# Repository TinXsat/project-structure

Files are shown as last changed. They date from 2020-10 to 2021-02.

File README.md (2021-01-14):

# project-structure

This repo is purely for discussing and planning the whole project's structure - what will communicate with what and how, how software will be organised, etc - whole "schema"

### Contributing :pencil:
All discusion and changes will be done through Pull Requests and Issues - commiting directly to master is officially illegal here  :no_entry_sign: :hand: :no_entry:

<sub><sub>[Inserting emojis](https://gist.github.com/rxaviers/7360908) into every single header is also required, and not respecting that will be punished 🔪 </sub></sub>

<!-- START doctoc generated TOC please keep comment here to allow auto update -->
<!-- DON'T EDIT THIS SECTION, INSTEAD RE-RUN doctoc TO UPDATE -->
**Table of Contents**

- [Mission :rainbow:](#mission-rainbow)
  - [Measurements of atmospheric pressure and temperature with subsequent data analysis :thermometer:](#measurements-of-atmospheric-pressure-and-temperature-with-subsequent-data-analysis-thermometer)
    - [Key goals :key:](#key-goals-key)
  - [Demonstration of cansat system for rescue operations during natural disasters :volcano:](#demonstration-of-cansat-system-for-rescue-operations-during-natural-disasters-volcano)
    - [Key goals :key:](#key-goals-key-1)
    - [Optional goals :small_blue_diamond:](#optional-goals-small_blue_diamond)
- [Satellite :satellite:](#satellite-satellite)
  - [Satellite launch :rocket:](#satellite-launch-rocket)
  - [Sensors aboard :thermometer:](#sensors-aboard-thermometer)
  - [Satellite 2 ground communication :phone:](#satellite-2-ground-communication-phone)
- [Ground station :radio:](#ground-station-radio)
- [Ground back-end server :computer:](#ground-back-end-server-computer)
- [Front-end :iphone:](#front-end-iphone)
- [Further data analisys :bar_chart:](#further-data-analisys-bar_chart)
- [Gantt timeline chart :alarm_clock:](#gantt-timeline-chart-alarm_clock)

<!-- END doctoc generated TOC please keep comment here to allow auto update -->

# Mission :rainbow:
## Measurements of atmospheric pressure and temperature with subsequent data analysis :thermometer:

### Key goals :key:

 - Measure of pressure and temperature outside the cansat.
 - Radio transmission of measurements data in minimal rate one packet per second.
 - Calculation of altitude based on atmospheric pressure.

## Demonstration of cansat system for rescue operations during natural disasters :volcano:

### Key goals :key:

 - Design system that meet following requirements:
 - low cost of produce
 - high accuracy
 - Access to information about position(GPS), altitude (barometer), temperature, acceleration
 - Take photos from the thermovision and visible range camera.
 - Mark on photos all obstacles (to protect rescuers) and places where people could possibly be.

### Optional goals :small_blue_diamond:

 - Investigate fire resistant biofiber composite with which body of cansat will be build
 - Pointing geographical coordinates of marked obstacles/humans.

# Satellite :satellite:
How the cansat sattelite will look and work to help us do the mission?

## Satellite launch :rocket:
How we will actually launching the sattelite (that is take it to 1.5km above)?

## Sensors aboard :thermometer:

## Satellite 2 ground communication :phone:
How our satellite will communicate with the ground station?

# Ground station :radio:
What is ground station and how it will work and pass us *the data* :chart_with_upwards_trend:?

# Ground back-end server :computer:
[Back-end server](https://github.com/TinXsat/server) takes care of receiving data from [ground station](#ground-station-radio),
parsing and processing it, and serving it to the [front-end](#front-end-iphone).
It also caches and saves any data that it received, in case satellite would fall apart

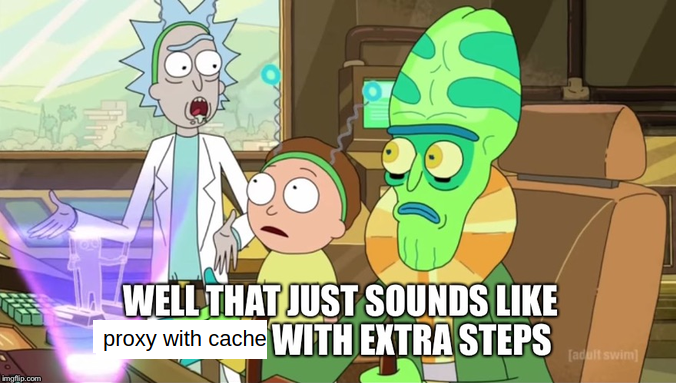
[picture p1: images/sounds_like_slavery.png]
Sounds like proxy+cache with extra steps


It is written in [Python](https://www.python.org/), and uses [Flask](https://flask.palletsprojects.com/) to serve a REST API

# Front-end :iphone:
[Our front-end](https://github.com/TinXsat/frontend) is a dashboard that will show us what is currently happening with the sattelite while it's in the air - for example, a map showing where the sattelite is right now, animation (like at SpaceX) about in what stage of the mission it currently is, etc

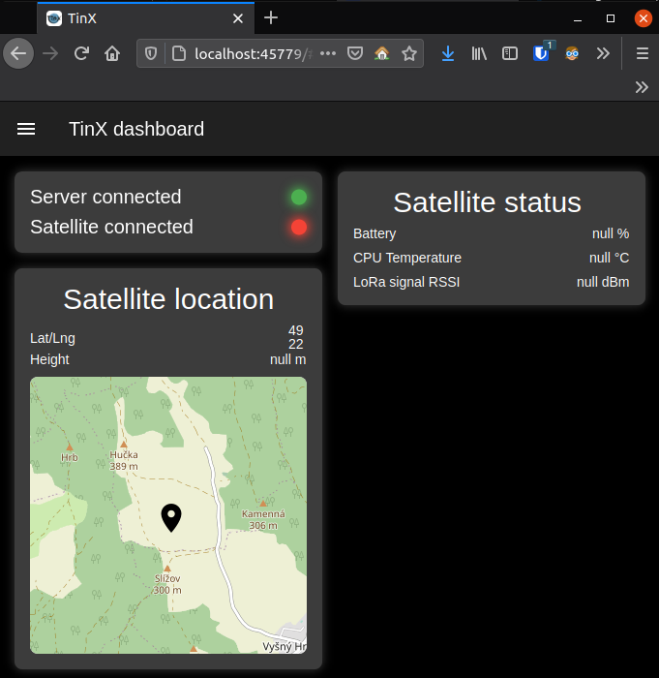
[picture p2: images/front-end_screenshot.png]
Screenshot of front-end


It is built in Flutter, and compiled to a web app. It gets data form [the server](#ground-back-end-server-computer) through REST endpoints, probably instantly, through localhost, since they will be hosted on same computer

# Further data analisys :bar_chart:
What we will further do with *the data* beyond the elements above?

# Gantt timeline chart :alarm_clock:

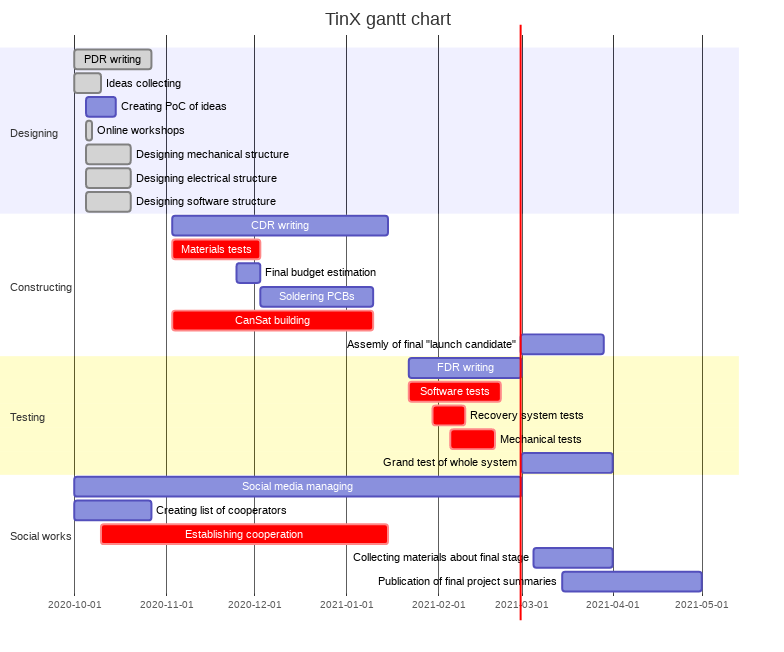
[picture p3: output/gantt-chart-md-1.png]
~mermaid diagram 1~


// You can view the code-block it in [gantt-chart.md](gantt-chart.md)

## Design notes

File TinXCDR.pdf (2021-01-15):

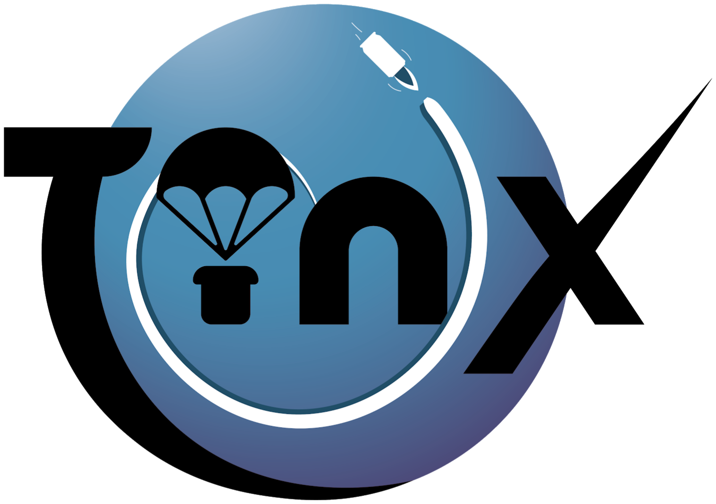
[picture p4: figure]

## TinX

## Technical High School no. 6 in Rzeszów

## Critical Design Review

CHANGELOG

3
INTRODUCTION

3
Team organisation and roles

3
Mission objectives

6
CANSAT DESCRIPTION

7
Mission overview

7
Mechanical/structural design

8
Electrical design

9
Software design | 18
Satellite software design | 18
Ground station software design | 20
Data analysis | 22
Recovery system | 23
Ground support equipment | 23
TEST CAMPAIGN | 24
Primary mission tests | 24
Secondary mission tests | 24
Communication system | 26
PROJECT PLANNING | 26
Time schedule | 26
Task list | 27
Budget | 27

External support | 28
Outreach programme | 28
CANSAT CHARACTERISTICS | 30

## CHANGELOG

## 1. INTRODUCTION

### 1.1. Team organisation and roles

Due to COVID-19 pandemic team started working online. We’re planning CanSat development during meetings on discord platform. Each team member dedicates one hour per week during meetings and members are prepared to dedicate needed time in after school time.

- 3 -
Date | Description | Page
2020-11-15 | Change goals for secondary mission | 6
2020-11-19 | New team member Aleksy Malawski | 6
2020-12-18 | Exclude inertial dampers | 8

- Ms. Anna Pękala (teacher)
Background:
Ms. Pękala has a Masters in Economics, and is a certified career counsellor. She has 15 years working experience with students in the fields of basic economics, entrepreneurship and career planning. Ms. Pękala has a number of interests, these include economics, psychology and personal development.
Field of work within team:
Ms. Pękala will be responsible for work planning and assignment of tasks. She will also be responsible for helping to motivate team members so that they can deliver their best work on this project. Ms. Pękala will also help members of the team to develop and grow through this process.
Ms. Pękala will also assist in management of the budget for this project, and assist in fundraising as necessary.
- Mikołaj Data (Team Leader).
Background :
Mikołaj Data is a student of Technical High School no. 6 in Rzeszów. He has extensive knowledge in the fields of programming, data analysis, electronics and astronautics. He has 6 years of experience in IT. Languages mainly used by him are C and Python.
Field of work with team:
He will be responsible for work planning, software and electronic development. His duties will also include website and social media managing.
- Przemysław Lib
- 4 -

Background :
Przemysław Lib is a 3D designer with many years of experience. Inventing useful devices and mechanisms is his passion. The programs he uses are Fusion 360 and Simplify 3D. He is a student of Technical High School no. 6 in Reszów.
Field of work with team:
His main task is to develop a safe recovery system, design CanSat’s body. He is also responsible for finding financial support in external sources.
- Filip Różak
Background:
Filip Różak has experience in designing and troubleshooting electronic devices from different fields: RF circuitry, SMPS, industrial, production, automation. Furthermore, he develops software for microcontrollers such as AVR, PIC, ARM mainly in the C language. He has great interest in creating robust and cheap solutions for everyone. Filip Różak is a student of Technical High School no. 6 in Rzeszów.
Fields of work with team:
His main task is to make design decisions about electronics in CanSat, develop schematics, circuit board(s) and write applications for onboard microcontrollers.
- Mateusz Soszyński
Background:
He is a full stack developer - has experience in many different aspects of programming - from embedded devices, to mobile apps, to managing Linux servers. He is also a passionate open-source community member, so he will be the most active in managing and maintaining our GitHub repositories.
- 5 -

Fields of work with team:
His main task is to take care of handling the data from satellites on the ground - processing and analyzing it on the back-end, and displaying it on the front-end.
- Aleksy Malawski
Background:
He is a graphic and motion designer. He is interested in animation and film editing. He has experience taking up many logos, illustration and motion design projects. Mostly creates his works using Adobe Illustrator and After Effects.
Fields of work with team:
He's responsible for creating posts, films and animation for teams' social media platforms.

### 1.2. Mission objectives

Due to some problems with cost of elements and COVID-19 pandemic, few of our goals was changed (see PDR report to see previous goals)
Primary mission: Measurements of atmospheric pressure and temperature with subsequent data analysis.
Key goals:
- Measurement of pressure and temperature outside the CanSat.
- Radio transmission of measured data in minimal rate one packet per second.
- Calculation of altitude based on atmospheric pressure assisted with geolocalization data.
- 6 -

- Measurement of temperature inside and outside the CanSat. To provide data about electronic parts performance.
Secondary mission: Demonstration of CanSat system for rescue operations during natural disasters.
Key goals:
- Design system that meet following requirements:
- Low cost of design and produce
- High accuracy and stability
- Easy access to information about position, altitude, temperature, acceleration
- Take photos from the visible range camera - and analyze them.
Optional goals:
- Investigate a fire resistant biofiber composite with which body of CanSat will be built, keeping cost as low as possible.
- Create an open access dataset for aerial photography classification.

## 2. CANSAT DESCRIPTION

### 2.1. Mission overview

Mankind is more often a bystander of natural disasters caused by global warming. Our project is focused on helping rescue teams during their hard work. Data gathered during the mission will be available for other engineers, scientists to help them improve their solutions.
The mission is being developed through a CanSat competition. Organisers of the competition provide a take-out system (rocket or UAV). CanSat on-board computer start is planned for +/- 2 hours before take-off. During take-off the satellite accelerometer will inform the on-board computer about rocket launch, then the
- 7 -primary mission starts. When CanSat will be deployed the secondary mission starts. Landing is predicted 4 minutes after deployment.

### 2.2. Mechanical/structural design

General objectives for the mechanical structure of the CanSat:
1. We will introduce the construction of CanSat inertial dampers to protect sensitive electronics, such as cameras, against vibrations and high acceleration stresses. - Canceled
2. The internal frame with electronics will be covered in a semi-fireproof shell made of fibers and ceramics.- Canceled
3. The internal frame will be printed with 3D technology, using nylon or materials with similar properties.- Included
4. Sensors will be placed in the external shell and will be connected by flexible wires to the main board.- Included

During development, we decided to exclude
dampers from the project. Tests showed that
small rubber pieces don't work as well as we
expected, | moreover | it | complicates | the
production process too much and weakens the connection between PCB bracket and internal frame of the canstat.
CanSats body still will be based on an internal PCB bracket screwed to the internal frame, but we recognised that our fireproof material is too heavy to use in cansat project. We made several different versions of fireproof material based on natural fibers but all of them were heavier than our assumptions. Instead of this we decided to use the
- 8 -

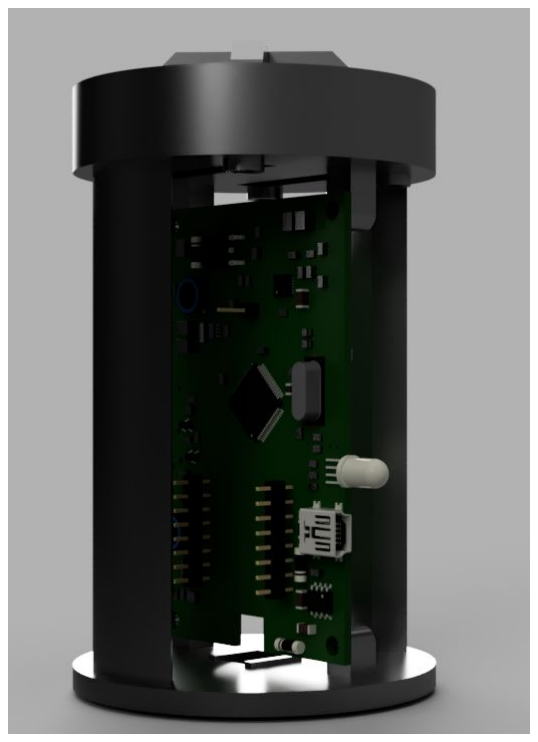
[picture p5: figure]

same material like we used to make canstats frames, that material is nylon reinforced with glass fibers.
During tests nylon reinforced with glass fibers met our expectation so we will use it in the final version of CanSat. That material will be used to make a PCB bracket, internal frame and also external body which will cover electronics and sensors. Sensors like barometer or thermometer will be glued with thermo-plastic glue to the external body. Barometers have to be protected against rush of air during the falling so we designed special channels which keep sensors inside of the case but also deliver atmospheric pressure to them.

## 2.3. Electrical design

General architecture
Electronic part of Cansat has been optimized for low-cost, highly efficient and fail-safe production process, assembly and operation. Usage of Off-the-shelf components has a significant impact on overall cost and opens a very cheap way to mass production.
Power supply
When in operation, device will be powered from li-on cells. This chemistry was chosen, because it’s comparably safe, operates well enough in a wide temperature range, is widely available, inexpensive and comes in almost every physical shape. To save space inside, flat (eg. phone) style batteries are used.
Li-on cells need to be charged properly - in CC and CV modes. Exceeding any of their normal parameters will decrease battery capacity and possibly damage the cells (or even the whole device due to explosion/leakage). Used batteries have protection circuits integrated inside. It protects individual cells against:
1. Over current discharge protection
2. Over discharge protection
- 9 -

To cover all of the battery requirements, also charging voltage and current has to be regulated. Most of this is done with just one physical chip (TP4056), which is a very common, cheap and trusted li-on cell charger. It does CC/CV modes switching, over charge protection.

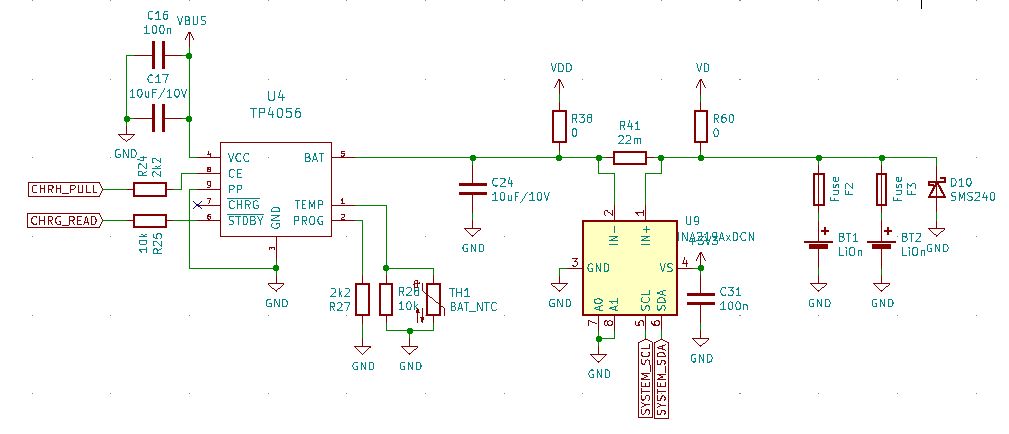
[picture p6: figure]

This part of the schematic shows the battery charging and monitoring system. F2 and F3 polyfuses protect against overcurrent/short circuit, if battery without protection inside is used. D10 protects circuit against connecting battery backwards. U9 measures battery voltage and current (using R41 shunt). U4 is an integrated charger with control/status pins connected to a microcontroller. Battery level can be estimated from voltage measured on battery (using U9) and/or calculating charged/discharged energy from battery.
Power management:
To optimize battery live - INA219 integrated bidirectional voltage/current sensors will be used. It makes power monitoring simple, reliable and cheap. INA219 has an integrated A/D converter and PGA, thus no additional analog components are not needed. This leads to very low price and efficient usage of PCB space (<1cm^2 for
- 10 -complete current/voltage measurement). Two of such monitors has been used across the board:
1. Measures battery charged/discharged current and battery voltage.
2. Measures battery voltage and current took by high voltage devices (Led Light and buzzer)
Creating System voltage rails:
Most of the IC’s on the board (including main controller) operate on 3.3V - thus there is a need of creating stable, reliable supply rail. To operate on the whole battery capacity - voltage must be stepped up (VBAT < 3.3V) or stepped down (VBAT > 3.3V). This can be achieved by using Buck-Boost converters such as TPS63001. It has integrated switches, automatic mode (Buck/Boost/passthrough) selection, Enable input (used to completely power off device) and operates on single, physically small inductor (due to high switching frequency: 1,2-1,5Mhz). At currents >100mA estimated efficiency of this converter is >80%.

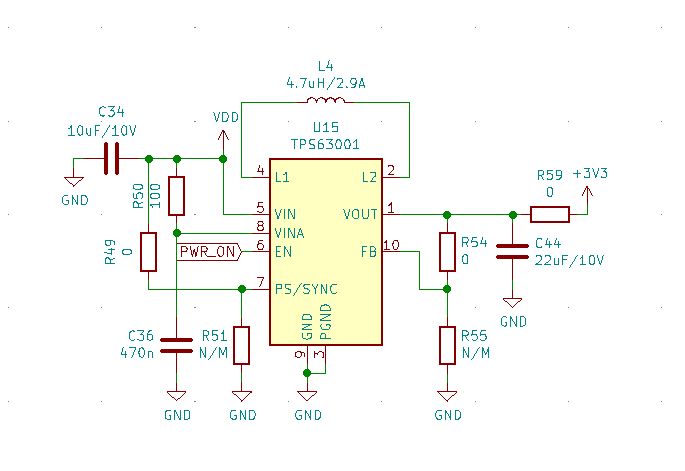
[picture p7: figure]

Creating 3.3V rail is very simple, and thus reliable using such an integrated converter. Low external components count minimizes board space taken by power management, to let more room for other circuitry.

- 11 -

To power Led Lightning with approx. 15V, stepping up of the voltage is needed (buzzer is also powered from this rail). TPS61175 integrated Step-up is used for this purpose. It’s small and simple to implement, guarantees high efficiency (>85%).

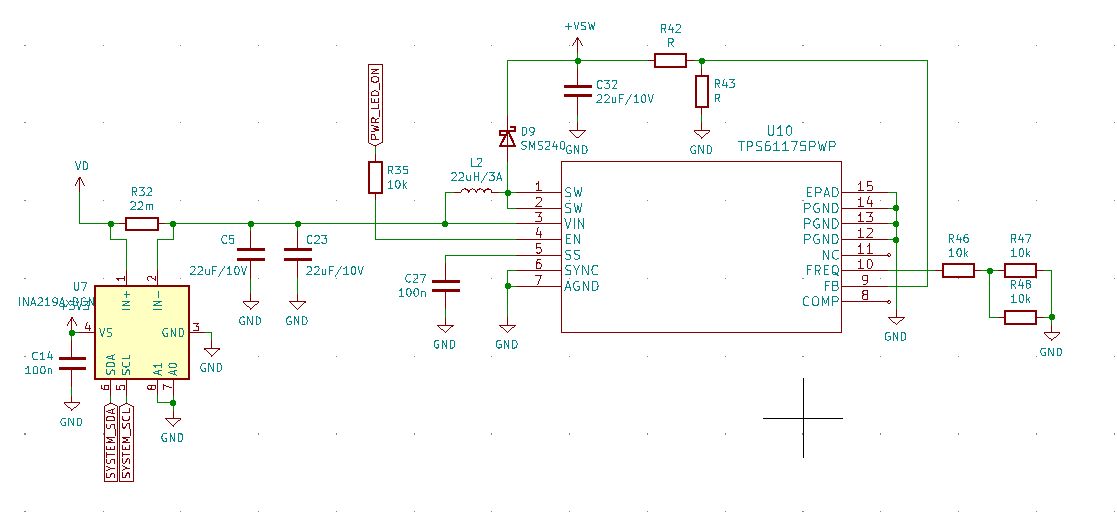
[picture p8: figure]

To keep EMI at a low level, and not disturb sensors in the device (or even other devices), proper layout of switching converters must be utilized.

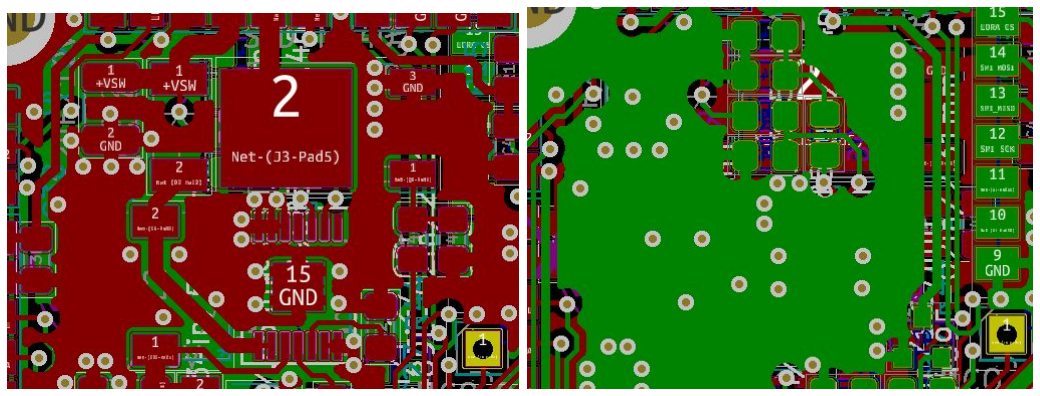
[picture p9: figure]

1. Ground plane under most noisy traces
2. Thick ground connection to switching components and bypass capacitors.
3. No analog traces near the converter
4. Concise structure of the whole converter.
- 12 -

Power-up logic:
In order to make the device operate only, when needed (save battery during transport and so on), power-up logic is implemented. To switch the device off, 3.3V converter “Enable” input is used.

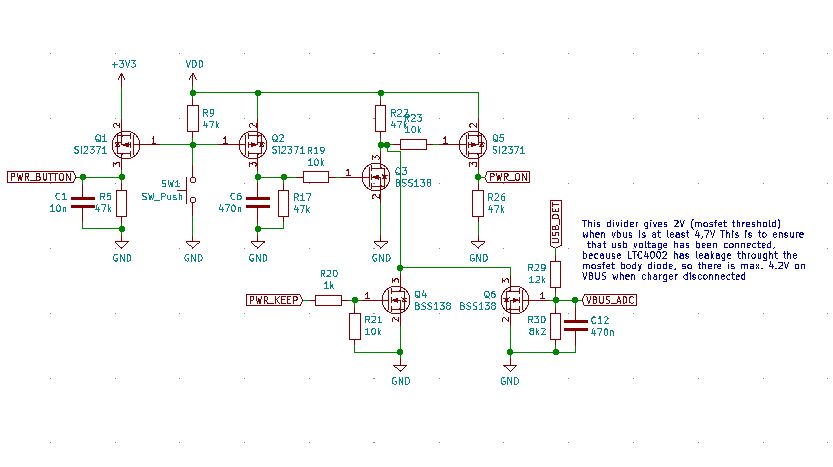
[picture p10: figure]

Microcontroller (and other circuitry on 3.3V rail) is powered only if:
1. Momentary button is pressed
2. Processor supplies power to itself
3. USB charging port is connected
This approach makes power-on sequence very reliable - cansat can be turned on by a momentary button, then a microcontroller starts up and latches power to itself (PWR_KEEP signal). Then - button can be used to power cansat down, but this function will be enabled only after the mission or corresponding lora command. This makes sure that no false power off will be triggered. Microcontroller also operates, when the USB charging port is connected - to show battery level on status LED, and integrate power injected to battery.
- 13 -

Estimating needed battery:
All values are maximal, worst case (in exact mode). Needed operating time is 3h in operation and 10h in standby (beacon).
- 14 -
Component | Operation | Standby
BMP280 x2 (Pressure + Temp) | 19uA * 200Hz = 3,8mA | 2,7uA
MPU6050 (Gyro+Accel) | 3,9mA | 500uA
A25l032 (Flash) | 21mA | 15uA
STM32F103RGT6 | 70mA (impossible - all pheripherials enabled, max speed) | 15uA
INA219 x2 (current measurement) | 1mA | 15uA
ESP32-CAM | 200mA | 20uA
Lora SX1278 | 120mA | 1.5u
Led lightning | 700mA 2/5 duty = 140mA | -
TPS63001 | 60uA | 1uA
TPS61175 | 3.5mA | 1.5uA
Buzzer circuit | 5mA | -
CP2102 | 26mA | 100uA
TP4056 | 6uA (from battery) | 6uA (from battery)
Genuine GPS receiver | 5mA | 200uA

We could do further calculations, but this data is not reliable - we are estimating power consumption of ~350mA when in operation and 2mA standby. Two 1,5Wh 3,7V Li-On cells with protection are used. Tests will show real values of consumed power.
Primary mission devices:
Primary mission of the device is to acquire temperature, pressure values, store them with altitude information and let the user read the data using a memory card. Radio communication will occur at least 1 time per second.
To measure Altitude and atmospheric pressure BMP280 sensors are used due to their numerous advantages:
1. Low cost
2. High reliability (tested in millions of devices)
3. Fast Data acquisition
4. Low power consumption
5. Simple to implement: I2C communication
6. Accurate enough, factory calibrated
To improve temperature data collection in speed domain (and relative accuracy) additional external sensors (LM35) are used - they have analog output and are physically small, this allows measurement of very fast temperature changes outside the device.
Main controller has been chosen, based on:
1. Low price
2. Good availability
3. Ease of programming/development. Evaluation board for this family exists.
- 15 -
Sum | 510mA | 1,4mA

4. Long production live (+10 years guaranteed)
5. Enough resources for possible expanding functionality
To meet all of the above, STM32F103RGT6 microcontroller has been selected. It has Cortex-M3 core, and a handful of useful pheripherials. It’s maximum frequency is 72Mhz on the core, and 36Mhz on fast periphs. All the inputs/supply pins operate at 3V3 logic levels, as well as every other chip on the board, so no level shifters are needed. This microcontroller also has automotive temperature range, clock save system and reliable BOR circuitry.
Secondary mission devices
Main goal of the secondary mission is
to make photos from the air, for further analysis. Usage of off-the-shelf cameras is not cheap enough for this device. However cheap ESP32-cam modules are available, they have reasonable capabilities compared to their very low price. Such modules integrate ESP32 processor together with external flash memory for firmware and camera connection. The
OV2640 camera can be used with the
module directly - it’s small, has 2Mpx

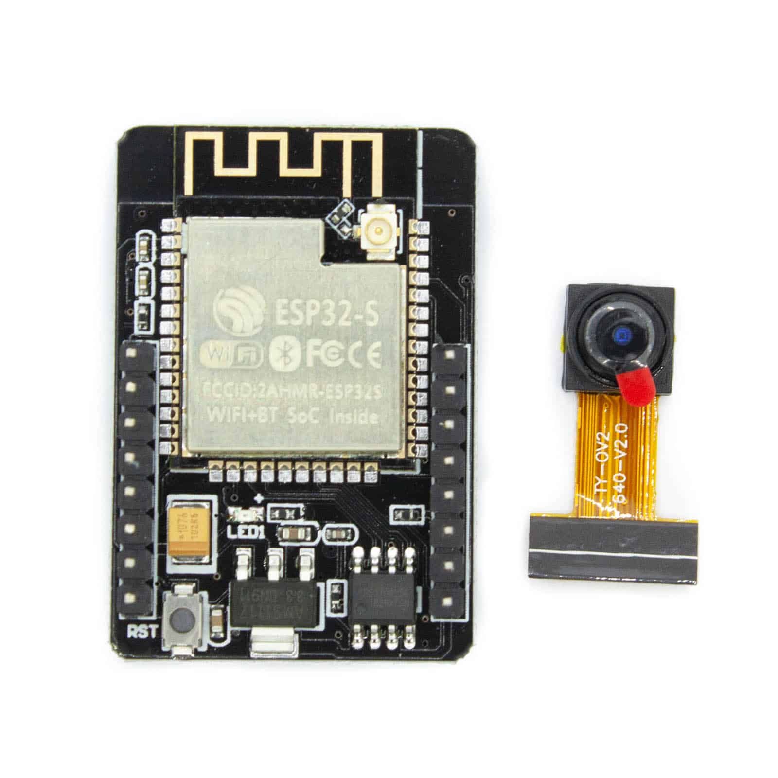
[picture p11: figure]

resolution and is very cheap. Usage of a secondary processor just for image handling is very efficient, because it has to be done as fast as possible and not interfere with other tasks. Images will be directly saved on memory card, due to their enormous size.
To obtain device rotation and acceleration in three-dimensional space (this is needed to determine mission phase and camera pointing direction), a gyroscope
- 16 -and accelerometer is used. MPU 5060 has been chosen due to it’s small physical dimensions, speed (measurement up to 1Khz) and low price. To achieve this performance, a separate I2C bus has been occupied as well as dedicated interrupt pin as well as frame synchronisation.
To obtain device geolocation position, a generic Telit GPS module is used. It uses a supercapacitor to keep satellite data in RAM, this allows for hot-start of the Receiver and makes overall fix time faster. Communication with the module is one-way.
All data, excluding photos, are saved to on-board flash memory - A25l032. It’s very fast (SPI speeds up to 100Mhz) and has internal ram for “per page” writing, which leads to even faster transactions on the bus, leaving processor time for other tasks than storing data.
Purpose of the Led light is to make the device visible and recognizable, when falling. Selected Light Emitting diodes are 3W 10000k white Bridge lux (4 of them). Every LED has a voltage drop of 3.5-3.7V. Connecting them in parallel to the battery is not an option, due to the fact that battery voltage can fall to 3,1 volts at normal operation (near discharge). Step up switching converter has been utilized to power the LEDs, connected all in series, which gives voltage of approx. 15V.
Communication system
Communication going to be performed in two ways:
1. From CanSat to ground station - acquired data, actual state, diagnostics
2. From ground station to CanSat - control commands
To communicate over a recommended distance of 3km s and meet power requirements, a highly efficient system has to be used. One of approaches to achieve that is to use a modulation technique optimized for low-power long-range
- 17 -transmission. Adequate tests have to be done, but from research can be seen, that LORA standart meets above requirements.
Selected LORA module is SX1278, in the RA-02 case. It communicates over SPI bus at speeds up to 10Mhz. During on-the-air transactions, it needs a maximum 600mA of current, so an appropriate capacitor bank has to be placed physically near the module and power traces should be thick enough.
All long range communication systems require tuned antennas, to increase connection budget (tuned antennas have connection budget profit). Possible antenna tuning will be possible with Vector Network Analyzer. As for the ground station antenna - GP type will be used, Cansat antenna is still under development.

### 2.4. Software design

Primary requirements for software in project:
1. Managing peripherals onboard CanSat.
2. Store and transmit data.
3. Analyse data.
To achieve all listed requirements software will be divided into three parts: satellite, ground station and algorithms for image analysis.
Software will be developed under GPLv3 license,

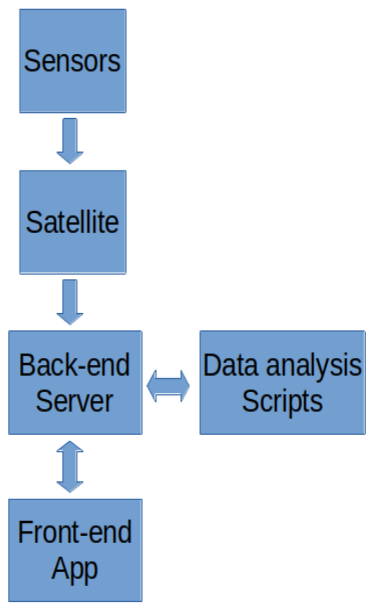
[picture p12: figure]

and shared on our Github ( | https://github.com/TinXsat | ).
Satellite software design
Satellite will be operating in 4 modes:
1. Before flight - calibration of sensors, low-level self test.
2. Lifting - data collection from accelerometer and possibly environment inside the rising system.
- 18 -

3. Falling - data collection and processing for on-board use. Execution of primary and secondary mission tasks. Maintenance of communication with the base station.
4. On the ground - enter low power mode, transmit recognition packets, possibly also with GSM. Fetch data to removable storage (sd card) for further analysis. To automatically distinguish between mission phases, state machine can be used. Such a system would take into account several variables: accelerometer reading, pressure (altitude). However, if some parameters would not be as assumed, the base station can send command to change mode.
Onboard data analysis will provide only basic information about the environment, due to limited processing power and speed needed to acquire data. Lack of operating system force usage of interrupts and timing peripherals of the microprocessor to implement multitasking, but also improves real-time operation synchronization.
Acquisition of such an amount of data from environmental sensors requires extensive averaging and filtering. To provide enough data to work with, high speed sampling has to be used.
Data communication with different onboard devices has to be solid and fail-save. In order to achieve that, extensive self testing of every funcional block has to be implemented. Software should report failure and (if possible) change/disable faulty block(s) and continue to work - this reduces downtime of the system in the air. Calibration procedure before flight will improve absolute accuracy of onboard sensors and their adaptation to different environmental conditions (atmospheric pressure changes rapidly even within a day).
To handle all of the needed auxiliary sensors, devices - several buses have to be used in the system:
1. SPI bus for SX1278 Lora module and Flash memory
- 19 -

2. I2C bus for MP6050 Gyroscope/accelerometer.
3. I2C bus for BMP280 sensors and INA219 meters.
4. RS232 (in 3V3 logic) for camera configuration/management
Each of those need to be handled separately, allowing pseudo multitasking for the system. This functionality is achieved by using various interrupts offered by the peripherals.

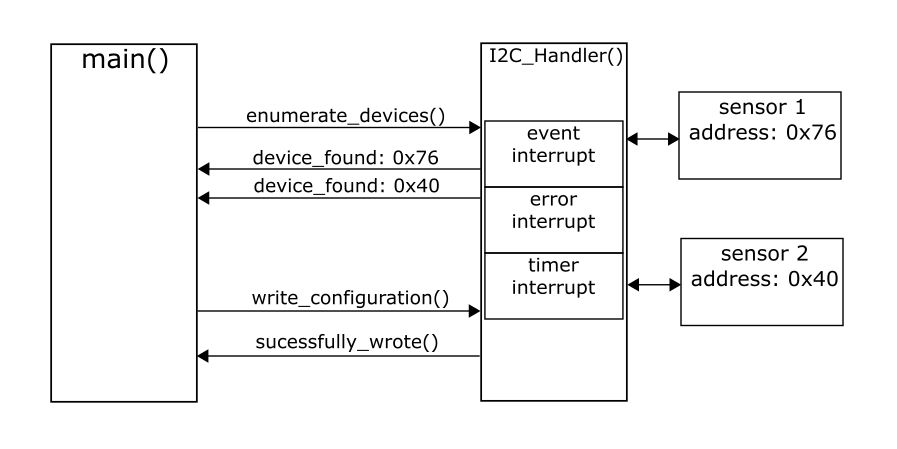
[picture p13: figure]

This picture shows the working principle of I2C_Handler - it creates an independent state machine, so the main program might be doing one thing, while busses are busy.

Ground station software design
Ground station will be responsible for collecting, storing, processing and presenting data received from CanSat. To handle all those tasks we are going to create a back-end server connected with a front-end app.
All changes in code are versioned with the “Git Flow” technique - every stable version has it’s semantic version code (for example 1.5.3), and is available to download in GitHub releases tab on it’s repository.
- 20 -

This way, we can easily debug which versions have certain bugs, and roll back to old ones if new changes cause problems.
Back-end server is the program that collects and processes the data received from the satellite.
Data from the radio receiver is read by USB UART serial, and saved in the database/csv files.
So essentially, it acts as a simple
proxy between LoRa and front-end,
and also records the data.
It is written in Python, and uses Flask to serve REST API for the front-end.
Repository:
https://github.com/TinXsat/server

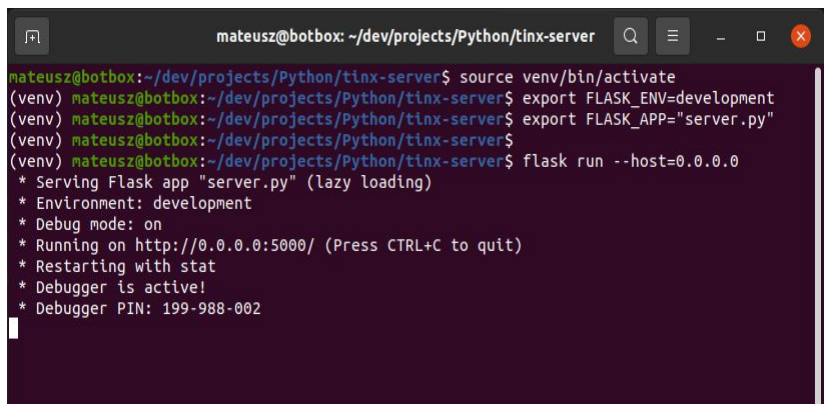
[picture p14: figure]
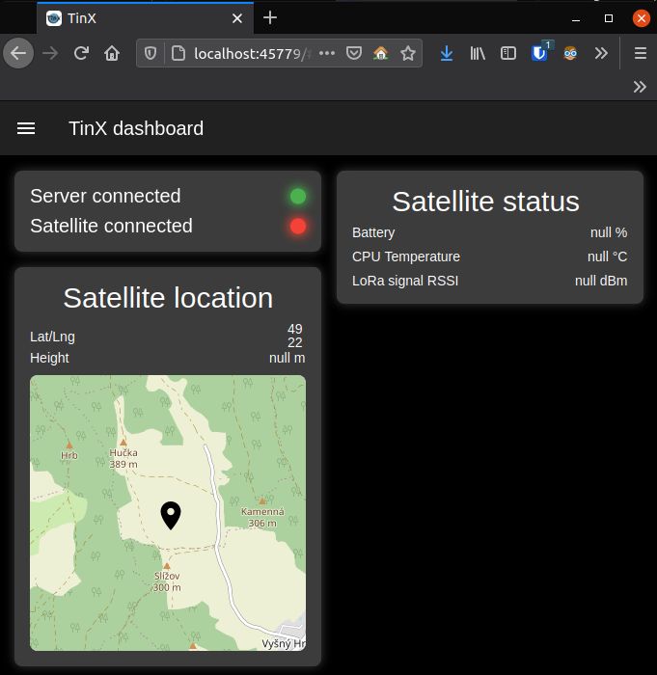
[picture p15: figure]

Front-end app, that is, everything that end-users interact with when our satellite launches. It is made with Flutter, because it’s cross-platform, fast to develop, and very easy to build good-looking UI. It will be served from the same computer where the back-end will live - no need to install any extra software for the end user. Repository:
https://github.com/TinXsat/frontend
- 21 -

Data analysis
To improve the development process of algorithms we migrate to Google Colab platform. All notebooks are stored in README.md in a repository for data analysis on GitHub.
Repository: https://github.com/TinXsat/data-processing-algorithms
Analyze flight telemetry. Thanks to sensors aboard CanSat we’ve got access to velocity, height, temperature inside and outside of CanSat. It’s very important to analyze all of it and draw conclusions. That data will help us to improve our device for next launches and future missions of the device.
Analyze photos. We are using a dataset created from videos publicly available on YouTube platform (https://www.kaggle.com/miki164/tinxsat ). Advantage of this solution is access to photos that will be very similar to photos gathered during CanSat launch. Disadvantage of this solution is the small size of the dataset (826 photos), so we have to use many augmentation techniques to make the dataset more useful.
Team develops algorithms for:
- Image segmentation (see more in | Secondary Mission Tests | )
- Generative adversarial network (GAN) to generate artificial images based on photos provided from cansat to augment dataset. (see more in Secondary Mission Tests )
- Road detection algorithms (works are now suspended due to small amount of images in dataset)
Next algorithms will be provided in the future.
To create the algorithms we are using Python and its data science libraries e.g: numpy, pandas, tensorflow, matplotlib. We are planning to develop neural
- 22 -networks and develop computer vision programs to make data gathered from CanSat more useful.
Data sharing
Data gathered during CanSat launch will be shared under MIT (or similar) license on Kaggle platform. It will give capability for other people to use data in their works.

### 2.5. Recovery system

Our recovery system is based on a parachute. That
solution is cheap, safe and reliable. Parachute will be a hexagonal shaped bowl made with light nylon fabric. Its dimensions will be 30x30 cm and were
calculated | by | using | a | website:
descentratecalculator.onlinetesting.net We expect 9.54 m/s free fall velocity. Parachute is attached to a special mounting on the top of the cansat.

### 2.6. Ground support equipment

Our ground equipment will contain:
- communication device
- antenna
- data processing unit

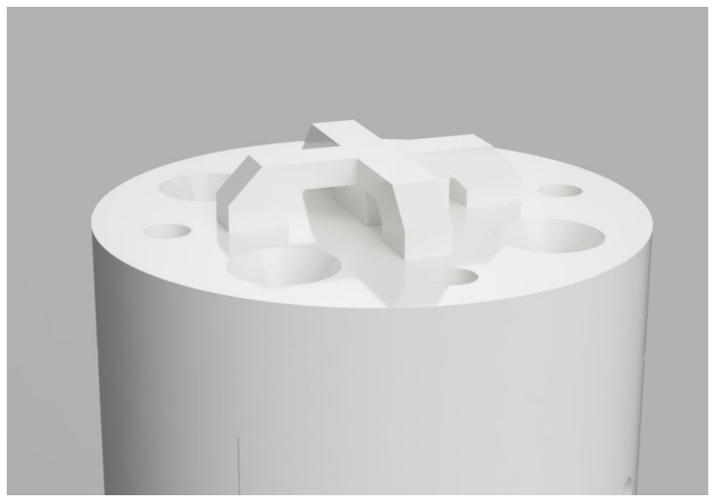
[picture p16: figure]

Communication device will be based on the radio receiver module, its task is to receive data from CanSat and pass it to the computer. It will cooperate with the antenna to extend transmission range.
Data processing unit will be a mobile computer with special software that will process data, save them, show in usable shape and share to other devices e.g. team members mobile phones.
- 23 -

## 3. TEST CAMPAIGN

### 3.1. Primary mission tests

Temperature and pressure measurement
To measure temperature and pressure - BMP280 sensors are used. For the test - a simple program has been written. It outputs data from sensors at a 100Hz rate over debug UART. RealTerm terminal emulator running on windows machine is used to receive this data.
Due to the fact that we don’t have any temperature standards, nor calibrated thermometer, accuracy stated by the datasheet has to be taken as an axiom. However, relative accuracy of pressure has been tested using the fact, that it corresponds to the altitude directly:
altitude = 44330 * (1.0 - pow(pressure / 1013hPa, 0.1903))
(simplified formula - optimized for speed on embedded systems)
One series of measurements was taken on the ground, and another on the third floor.
Results: Average pressure measurements were:
1. On the ground: 990.6hPa (190.27m)
2. On the 8.5m over the ground: 989.6hPa (198.75m) It gives a difference of 8.48m, which is good.

## 3.2. Secondary mission tests

Notebooks used in tests
1. https://colab.research.google.com/drive/1wgNq5ZRyhjGuFB5EDJgYtSbQyw5s14Gt?usp=sharing (https://colab.research.google.com/drive/1wgNq5ZRyhjGuFB5EDJgYtSbQyw5s14Gt?usp=sharing)
- 24 -

2. https://colab.research.google.com/drive/1PM4GragHtV4pXwYbwWQrfmQu8L9xn6lM?usp=sharing (https://colab.research.google.com/drive/1PM4GragHtV4pXwYbwWQrfmQu8L9xn6lM?usp=sharing)
Choosing segmentation algorithm 1
First step in developing image processing was choosing an
image segmentation algorithm. We compared two most popular algorithms KMeans (left) and GaussianMixture (right).
Results: We choose that we try to use both algorithms, because segmented images are very similar. Next tests are needed to determine which algorithm is better.
Plotting segmented images 2
Team created notebooks with

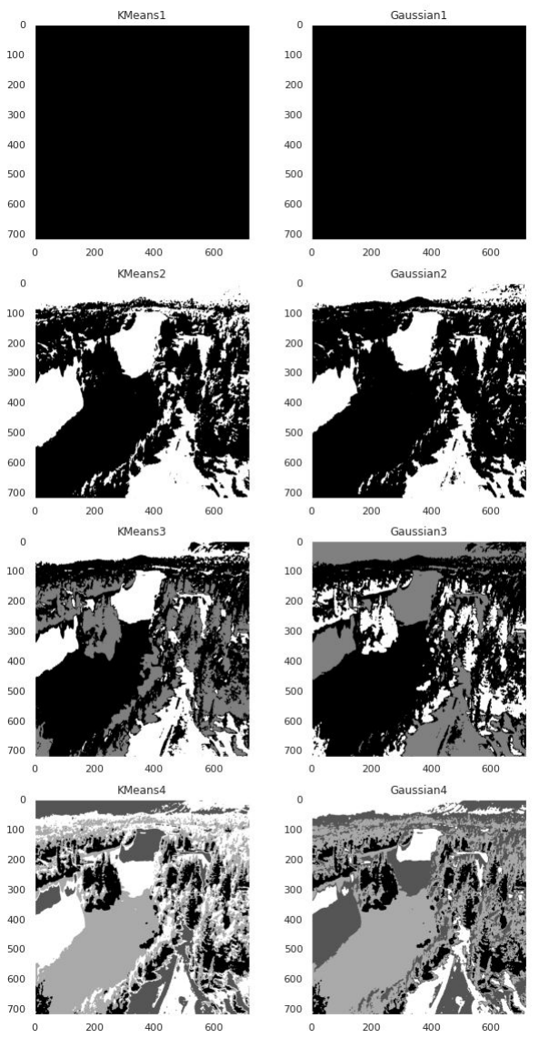
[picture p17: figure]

algorithms to segment images. We plotted segmented images (left) and grayscale images (right) to present results of segmentation.

Results: Comparison of images shows that segmentation works properly and it can be used for training the neural network and future data
processing.

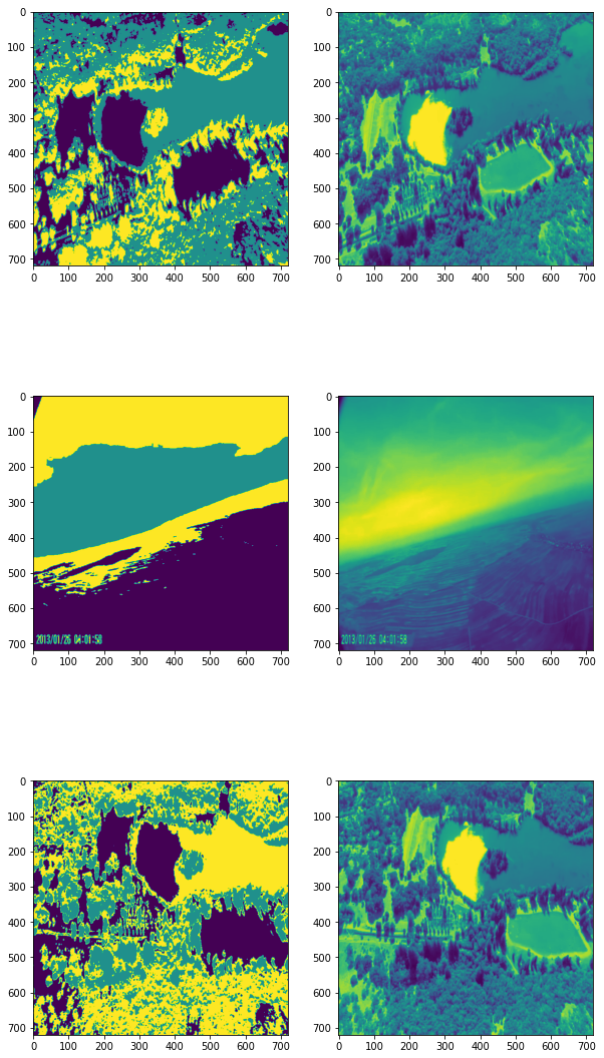
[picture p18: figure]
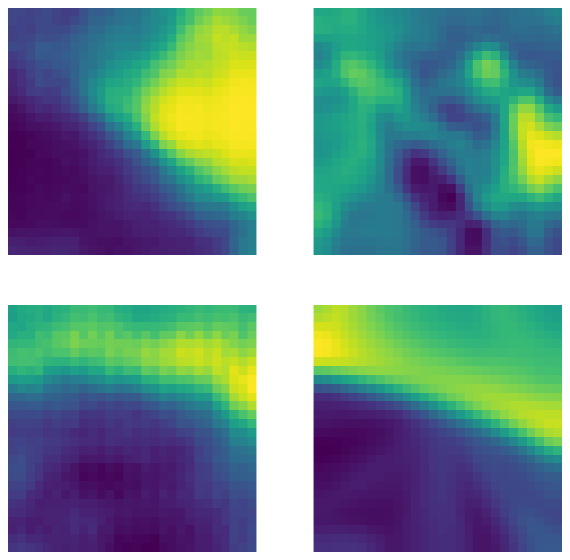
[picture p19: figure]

Deep Convolutional Generative adversarial network (DCGAN) for artificial image generation The original dataset is too small (826 photos), so the team created the GAN to augment the

- 25 -dataset. It will help in future analysis of CanSat flight and in expanding the capabilities of our solution.
Results: Network made by team works well on photos with 28x28 (pictures on right are generated by GAN, pictures on left are from dataset) size, but on higher resolutions model returns random values. After some research we are planning to
test HDCGAN ( | https://arxiv.org/pdf/1711.06491v12.pdf) | .

## 3.3. Communication system

Lora range test
For this test - antennas had not arrived yet, but we tried the lora communication with standard ¼ wavelength antennas (piece of wire with length of 165mm). Polarization was vertical, but unfortunately - antennas were on the same height. This was due to the lack of high enough buildings around.
Results: RSSI which lora can safely work with reaches around -100dB, and sometimes caches even -120dB. Distance, at which RSSI got to -100dB was around 600m away, with lots of buildings and no direct line of sight (needed for high frequency - 433Mhz communication). With such simple antennas - this is more than expected in this environment, in the air it would be at least x2.5 times longer distance. However, on the specially tuned antennas (GP on the ground and Dipole on the air) we expect around 3km range.

## 4. PROJECT PLANNING

### 4.1. Time schedule

Time schedule is created using https://github.com/mermaid-js/mermaid

- 26 -

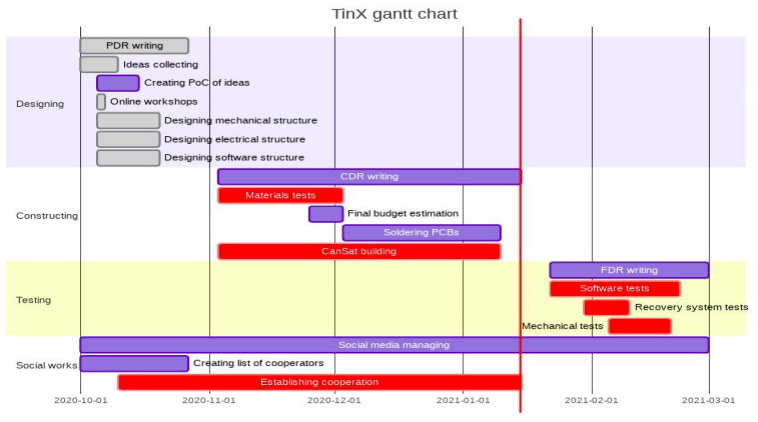
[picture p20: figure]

## 4.2.Task list

Team task list is updated in real time and is shared on Github platform. (https://github.com/orgs/TinXsat/projects/1 )

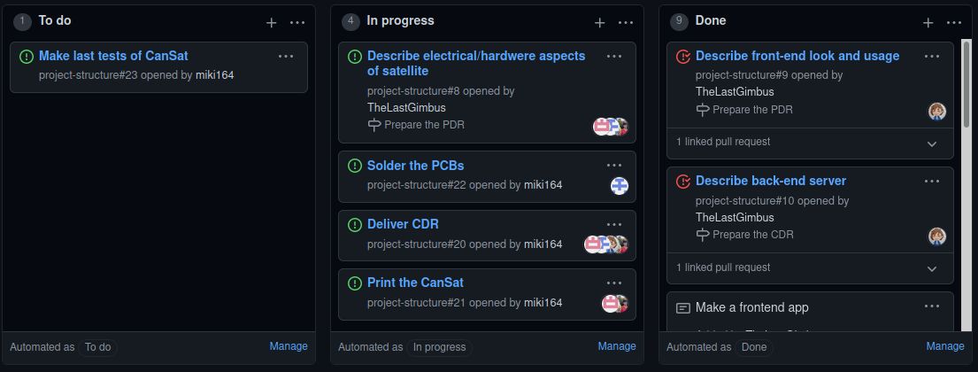
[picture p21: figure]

### 4.3. Budget

- 27 -
No. | Part name | Quantity | Price per piece [EUR]
1. | STM32F103 | 1 | 3

### 4.4. External support

In order to obtain support, the team established cooperation with:
- Nettigo.pl - sponsor and electronic parts provider
- Kolegium Nauk Przyrodniczych Uniwersytetu Rzeszowskiego - substantive assistance and rental of research equipment
- PcbGoGo - PCB manufacturer
- qlrs.pl - the antennas manufacturer
- Blue Dot Solutions - substantive assistance and team advertising
- Kosmonauta.net - substantive assistance and team advertising
- Gabriel Gałęza - website design and development
- Szymon Mytych - website design and development
- 28 -
2. | MPU6050 | 2 | 1
3. | BMP280 | 2 | 1
4. | INA219 | 2 | 2
5. | ESP32CAM | 2 | 5
6. | TP4056 | 1 | 1
7. | Led lighting | 1 | 2
8. | Battery | 2 | 3
9. | sx1278 | 1 | 8
TOTAL: | | | 38

### 4.5. Outreach programme

During the competition team started:
- Website - | tinxsat.github.io | - addressed to our cooperators or future cooperators
- Fanpage | on | facebook -
fb.com/tinxsat - created to
encourage | people | to
programming and creating
space projects.
Fanpage got 90 likes. We were creating posts that could reach 2000 people. Posts were
created regularly.
- YouTube channel - created to

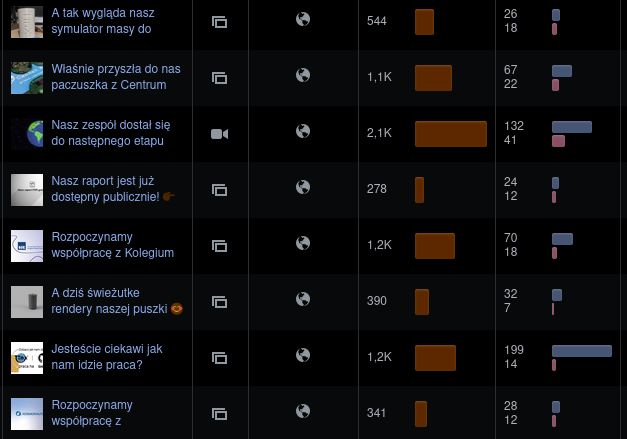
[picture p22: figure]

encourage people to programming and creating space projects.
- Github organisation - github.com/tinxsat/ - addressed for programmers, data scientists. It creates opportunity to get more help from open-source developers community
- An email - tinxasat@gmail.com - created to communicate with companies, cooperators and government agencies.
We were focused on creating posts regularly to maximize posts reach. Team also created a promotional video (https://youtu.be/_mBKociq5aw ) to promote the project and encourage potential sponsors to cooperate. The outreach programme was one of the most important parts of the project thanks that we obtained many support from companies and other people.
An article was created about the team on the kosmonauta.net portal (https://kosmonauta.net/2021/01/rzeszowski-zespol-kontynuuje-prace-w-konkursie-cansat-jaka-jest-ich-misja/ (https://kosmonauta.net/2021/01/rzeszowski-zespol-kontynuuje-prace-w-konkursie-cansat-jaka-jest-ich-misja/) ).
- 29 -

## 5. CANSAT CHARACTERISTICS

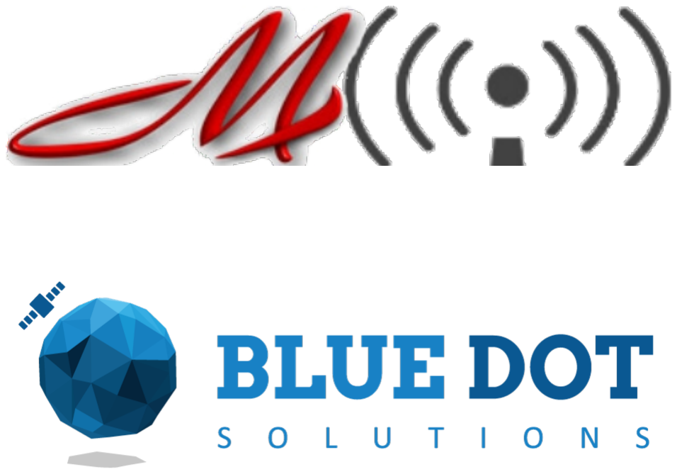
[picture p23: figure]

- 30 -
Characteristics | Figure
Height of the CanSat | 113.8mm
Diameter of the CanSat | 65mm
Estimated mass of the CanSat | 348g
Estimated descent rate | 9.54m/s
Radio transmitter model | SX1278
Estimated time on battery (primary mission) | 8 hours
Cost of the CanSat | 38 EUR

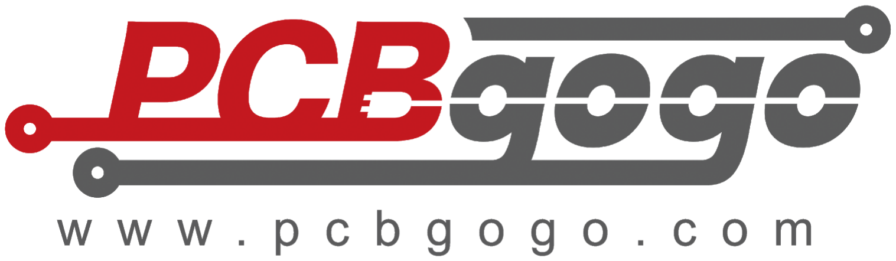
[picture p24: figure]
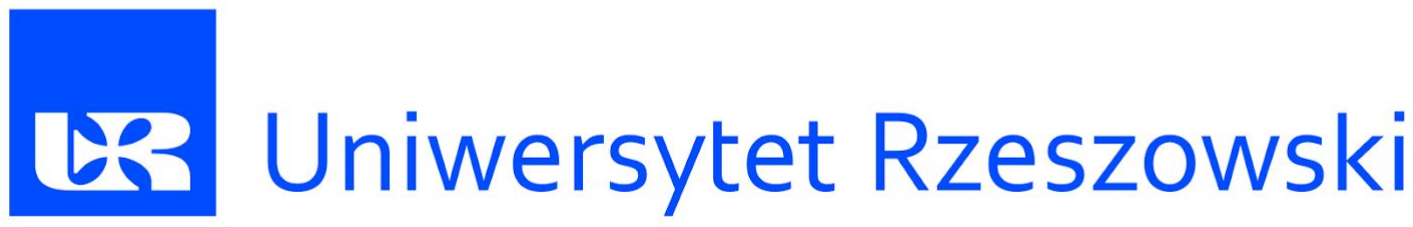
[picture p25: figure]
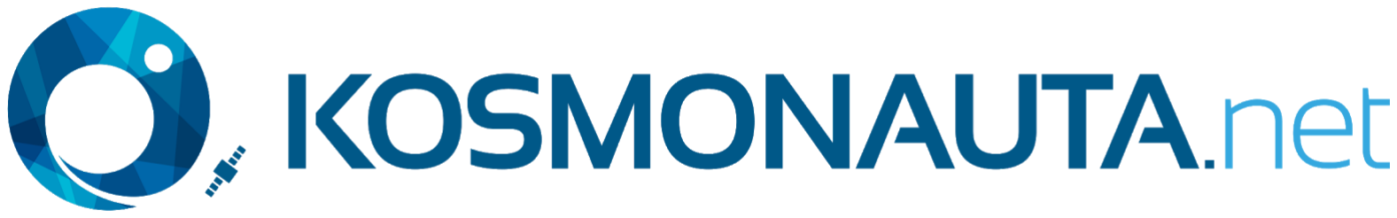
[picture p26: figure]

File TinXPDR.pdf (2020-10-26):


## Team Name: TinX

## Country: Poland

INTRODUCTION

3
Team organisation and roles

3
Missions objectives

5
CANSAT DESCRIPTION

6
Mission overview

6
Mechanical/structural design

7
Electrical design

8
Software design | 12
Satellite software design | 12
Ground station software design | 13
Scripts for data analysis | 14
Recovery system | 14
Ground support equipment | 15
PROJECT PLANNING | 16
Time schedule | 16
Task list | 17
Budget | 17
External support | 18
Outreach programme | 18

## 1. INTRODUCTION

### 1.1. Team organisation and roles

Each team member dedicates one hour per week during meetings in school and members are prepared to dedicate needed time in after school time.
- Ms. Anna Pękala (teacher)
Background:
Ms. Pękala has a Masters in Economics, and is a certified career counsellor. She has 15 years working experience with students in the fields of basic economics, entrepreneurship and career planning. Ms. Pękala has a number of interests, these include economics, psychology and personal development.
Field of work within team:
Ms. Pękala will be responsible for work planning and assignment of tasks. She will also be responsible for helping to motivate team members so that they can deliver their best work on this project. Ms. Pękala will also help members of the team to develop and grow through this process. Ms. Pękala will also assist in management of the budget for this project, and assist in fundraising as necessary.
- Mikołaj Data (Team Leader).
Background :
Mikołaj Data is a student of Technical High School no. 6 in Rzeszów. He has extensive knowledge in the fields of programming, data analysis, electronics and astronautics. He has 6 years of experience in IT. Languages mainly used by him are C and Python.

3

Field of work with team:
He will be responsible for work planning, software and electronic development. His duties will also include website and social media managing.
- Przemysław Lib
Background :
Przemysław Lib is a 3D designer with many years of experience. Inventing useful devices and mechanisms is his passion. The programs he uses are Fusion 360 and Simplify 3D. He is a student of Technical High School no. 6 in Reszów.
Field of work with team:
His main task is to develop a safe recovery system, design CanSat’s body. He is also responsible for finding financial support in external sources.
- Filip Różak
Background:
Filip Różak has experience in designing and troubleshooting electronic devices from different fields: RF circuitry, SMPS, industrial, production, automation. Furthermore, he develops software for microcontrollers such as AVR, PIC, ARM mainly in C language. He has great interest in creating robust and cheap solutions for everyone. Filip Różak is a student of Technical High School no. 6 in Rzeszów.
Fields of work with team:
His main task is to make design decisions about electronics in CanSat, develop schematics, circuit board(s) and write applications for onboard microcontrollers.

4

- Mateusz Soszyński
Background:
He is a full stack developer - has experience in many different aspects of programming - from embedded devices, to mobile apps, to managing Linux servers. He is also a passionate open-source community member, so he will be the most active in managing and maintaining our GitHub repositories.
Fields of work with team:
His main task is to take care of handling the data from satellite on the ground - processing and analyzing it on the back-end, and displaying it on the front-end.

### 1.2. Missions objectives

Primary mission: Measurements of atmospheric pressure and temperature with subsequent data analysis.
Key goals:
- Measurement of pressure and temperature outside the CanSat.
- Radio transmission of measured data in minimal rate one packet per second.
- Calculation of altitude based on atmospheric pressure assisted with geolocalization data.
Secondary mission: Demonstration of CanSat system for rescue operations during natural disasters.
Key goals:
- Design system that meet following requirements:

5

- Low cost of design and produce
- High accuracy and stability
- Easy access to information about position, altitude, temperature, acceleration
- Take photos from the thermovision and visible range camera - merge them and analyze.
- Mark on photos all obstacles (to protect rescuers) and places where people could possibly be.
Optional goals:
- Investigate a fire resistant biofiber composite with which body of CanSat will be built, keeping cost as low as possible.
- Pointing geographical coordinates of marked obstacles/humans basing on gyro data.

## 2. CANSAT DESCRIPTION

### 2.1. Mission overview

The mission is being developed through a CanSat competition. The organisers of the competition provide a take-out system (rocket or UAV). CanSat on-board computer start is planned for +/- 2 hours before take-off. During take-off the satellite accelerometer will inform the on-board computer about rocket launch, then the primary mission starts. When CanSat will be deployed the secondary mission starts. Landing is predicted 4 minutes after deployment.

6

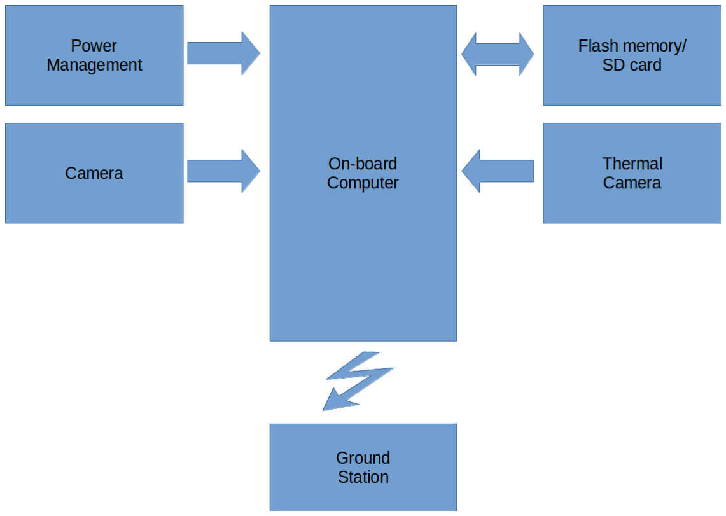
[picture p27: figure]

Primary and secondary mission diagrams

### 2.2. Mechanical/structural design

General objectives for the mechanical structure of the CanSat:
1. We will introduce the construction of CanSat inertial dampers to protect sensitive electronics, such as cameras, against vibrations and high acceleration stresses.
2. The internal frame with electronics will be covered in a semi-fireproof shell made of fibers and ceramics.
3. The internal frame will be printed with 3D technology, using nylon or materials with similar properties.
4. Sensors will be placed in the external shell and will be connected by flexible wires to the main board.
The inertial dampers will be 3D printed using flexible material with properties similar to hard rubber. Such a solution will protect our main board and cameras against high acceleration while being lifted by rocket and will protect physical data storage in case of parachute failure on landing.
The fireproof case will be made with some cheap bio fiber like paper or flax, glued in the shape of a cylinder. Next, the cylinder will be soaked with a sodium

7

silicate water solution (water glass) which will make it hard, fireproof and waterproof.
The internal frame will be connected with inertial dampers to the external shell. The main board, power supply system and other electronic parts will be attached to it. We expect to make it with nylon, because that material has high impact strength and is insensitive to heat up to 170 degrees Celsius.
Sensors will be placed in the external shell to let them make reliable measurements. Connecting them to the main board by using flexible wires will allow internal frame movement in the field of inertial dampers without breaking connection with the sensors.

## 2.3. Electrical design

General architecture
Primary requirements for electronics in Cansat:
1. Usage of double/triple redundancy for each physical component to improve fail-safe operation and robustness.
2. Accurate measurement of several electrical parameters inside the system in order to provide information about possible failures and their sources.
3. Usage of low-cost widely available, off-the-shelf components to allow for decreased budget on electronics part and make it more affordable.
4. Physically robust construction of PCB.
To answer all needs a versatile digital control is required. Acquisition and interpretation of different kinds of data requires speed and plenty of memory. Modern Uc's with 32 bit cores are extremely low-cost, fast and have a lot of useful pheripherials. This leads to the use of a STM32F103RG as main controller. Reliability and redundancy, used widely in self-driving cars, are main challenges to deal with, while keeping cost as low as possible. To improve MTBF (mean

8

time between failures) all parts of the system will have hardware support for self-testing.
Data Acquired from all sensors/cameras are stored in Flash memory (external physical chip), due to simplicity to use, high speed (SD card needs file system initialization and handling). Data can be protected from corruption using CRC calculation and checking, usage of two separate physical chips increases reliability. When the mission is complete, data will be transferred to the micro SD card (easy to use for operator).
Primary mission devices:
Usage of sensors combined in one physical device usually leads to lower accuracy and reliability. Thus sensor systems have to be constructed from individual probes and digitalization circuits.
Some of the environmental sensors need exact airflow and/or protection against atmospheric conditions. This creates a need for their physical alignment.
Main task of primary mission devices is to acquire required data with as high as possible accuracy and reliability, to simplify processing of the results. Temperature measurement has to be very linear, because predicted temperature variations will be relatively small. Absolute error can be easily reduced by implementing a calibration procedure.
To measure temperature several probes can fulfill its task:
1. Thermocouple - needs high accuracy, low drift and low offset voltage amplifier
2. Resistive sensor - needs nonlinearity compensation and stable reference
3. Off-the-shelf digital sensor - needs high price for high accuracy, however simple to implement

9

Further tests have to be done to distinguish which one(s) to use.
Measuring atmospheric pressure is used to calculate altitude together with the geolocation system, thus is very important. Development of own pressure probe and indirect measurements (eg. through frequency) using it are tricky and might not provide linear results. In this case using industry standard sensors (eg. BMP-280 from Bosch Sensortec) improves reliability and performance. Due to the high importance of pressure measurement redundancy is required here. Stable reference voltages and/or current sources are required for stable measurements across the whole ranges. Also, there could be a need of keeping some delicate measurement circuitry under stable conditions (e.g. temperature, humidity).
Secondary mission devices
Accelerometer and gyroscope are needed to provide information about the actual relative position and rotation of the device. Collected data will be used in the ground station, but they also have to be analyzed onboard to recognize mission steps. Those sensors can be embedded in one physical chip - this simplifies layout and allows for physical redundancy, due to reduced size.
To calculate the actual device’s position on the earth, a geolocation data receiver can be used. Support for different geolocation systems (GPS, Glonass, Galileo) makes results more accurate (especially over different continents). Camera operation requires acquisition, storage and processing of huge amounts of data. Moreover, data has to be fetched extremely fast and simultaneously in both cameras, due to the relatively high falling speed of CanSat. To do that cheaply, a main microcontroller can be used. However if it turns out that it's too slow - external FPGA can also be utilized as camera handling logic. Pcb layout has to be optimized mainly for camera operation, due to high operating frequency, in order keep EMI as low as possible and reduce interference with other components.

10

Power supply
As there seems to be lack of power management solutions for such projects -own has to be developed and tested. This will further improve control over the system. Moreover, in this kind of low-power application efficiency is required along with low EMI emission to meet electromagnetic compatibility requirements and to not disturb delicate sensors. Battery should have not less capacity to let CanSat inform about it’s position for several hours, chemistry has to be chosen during initial tests.
Communication system
Communication going to be performed in two ways:
1. From CanSat to ground station - acquired data, actual state, diagnostics
2. From ground station to CanSat - control commands
To communicate over a recommended distance of 3km s and meet power requirements, a highly efficient system has to be used. One of approaches to achieve that is to use a modulation technique optimized for low-power long-range transmission. Adequate tests have to be done, but from research can be seen, that LORA standart meets above requirements.
All long range communication systems require tuned antennas, to increase connection budget (tuned antennas have connection budget profit). Possible antenna tuning will be possible with Vector Network Analyzer.
To facilitate finding CanSat after landing, a GSM network can be used to transmit device’s localization, however GSM network doesn't have coverage on the whole globe, thus communication cannot rely on this type of communication.
To improve fail-safe operation and communication reliability, different (possibly high power) transmission could be developed if needed.

11

### 2.4. Software design

Primary requirements for software in project:
1. Managing peripherals onboard CanSat.
2. Store and transmit data.
3. Analyse data.
To achieve all listed requirements software will be divided into three parts: satellite, ground station and algorithms to image analysis. Software will be developed under GPLv3 license, so source code will be shared on our
Github( | https://github.com/TinXsat | ).

Satellite software design
Satellite will be operating in 4 modes:


1. Before flight - calibration of sensors, low-level self test.
2. Lifting - data collection from accelerometer and possibly environment inside the rising system.
3. Falling - data collection and processing for on-board use. Execution of primary and secondary mission tasks. Maintenance of communication with the base station.
4. On the ground - enter low power mode, transmit recognition packets, possibly also with GSM. Fetch data to removable storage (sd card) for further analysis.
To automatically distinguish between mission phases, state machine can be used. Such a system would take into account several variables: accelerometer reading, pressure (altitude). However, if some parameters would not be as assumed, the base station can send command to change mode.

12

Onboard data analysis will provide only basic information about the environment, due to limited processing power and speed needed to acquire data. Lack of operating system force usage of interrupts and timing peripherals of the microprocessor to implement multitasking, but also improves real-time operation synchronization.
Acquisition of such an amount of data from environmental sensors requires extensive averaging and filtering. To provide enough data to work with, high speed sampling has to be used. Luckily DMA can be utilized for some of these tasks to unload core and let it perform other operations.
Data communication with different onboard devices has to be solid and fail-save. In order to achieve that, extensive self testing of every funcional block has to be implemented. Software should report failure and (if possible) change/disable faulty block(s) and continue to work - this reduces downtime of the system in the air.
Calibration procedure improves absolute accuracy of onboard sensors and their adaptation to different environmental conditions (atmospheric pressure changes rapidly even within a day).

Ground station software design
Ground station will be responsible for collecting, storing, processing and presenting data received from CanSat. To handle all those tasks we are going to create a back-end server connected with a front-end app.
Back-end server is the program that will collect and process the data received from satellite - will be fully written in Python, because it’s one of the fastest to develop, popular and most versatile languages out there.
Data from the radio receiver will be read by USB UART serial, and saved in the database/csv files.

13

While receiving the data, the server will be able to push it on-the-fly to the front-end app, through http API.
Front-end app that is, everything that end-users interact with when our satellite launches. It will be made with Flutter, because it’s cross-platform, fast to develop, and very easy to build good-looking UI.
Thanks to its ability to compile to a web app, it could be served from the same server where the back-end will live - no need to install any extra software for the end user.
All of it’s changes (while developing it) will be versioned with the “Git Flow” technique.


Scripts for data analysis
To make our code more readable, the team
decided that we create a special repository only for scripts to data processing. To create them we will use Python and its data science libraries e.g: numpy, pandas, matplotlib.
To provide accurate position of located objects scripts will be based on 3D terrain models (see picture).

### 2.5. Recovery system

Our recovery system will be based on a parachute. That solution is cheap, safe and reliable. Parachute will be a hexagonal shaped bowl made with light nylon fabric. Its dimensions will be 30x30 cm and were
calculated | by | using | a | website:
descentratecalculator.onlinetesting.net | We

14


expect 9.54 m/s free fall velocity. Parachute will be attached to four fasteners on the top of CanSat using paracord strings.

### 2.6. Ground support equipment

Our ground equipment will contain:
- communication device
- antenna
- data processing unit
Communication device will be based on the radio receiver module, its task is to receive data from CanSat and pass it to the computer. It will cooperate with the antenna to extend transmission range.
Data processing unit will be a mobile computer with special software that will process data, save them, show in usable shape and share to other devices e.g. team members mobile phones.

15

## 3. PROJECT PLANNING

### 3.1. Time schedule

Time schedule is created using https://github.com/mermaid-js/mermaid


16

## 3.2.Task list

Team task list is updated in real time and is shared on Github platform. (https://github.com/orgs/TinXsat/projects/1 )


### 3.3. Budget

In this document we only present our budget forecasts. We are going to provide more accurate budget estimation in next document revision.

No. | Part name | Quantity | Price per piece [EUR]
1. | Microcontroller | 1 | 7
2. | Temperature Sensor | 2 | 2
3. | Camera | 1 | 10
4. | Thermovision camera | 1 | 30
5. | Accelerometer | 2 | 4.5
6. | Barometer | 2 | 4.5

17

7. | 3D printing materials | 1 kg | 10
8. | PCB board making | 3 | 10
9. | Rest of electronics | - | 10
10. | Recovery system | 1 | 7
11. | Battery | 1 | 5
TOTAL: | | | 100

### 3.4. External support

In order to obtain support, the team established cooperation with:
- Kolegium Nauk Przyrodniczych Uniwersytetu Rzeszowskiego - substantive assistance and rental of research equipment
- Blue Dot Solutions - substantive assistance and team advertising
- Kosmonauta.net - substantive assistance and team advertising
- Aleksy Malawski - graphical design
Now the team is looking for a funding source. Team plans to start cooperation with producers of filament to 3D printing and government agencies.

### 3.5. Outreach programme

Our team started:
- Website - tinxsat.github.io - addressed to our cooperators or future cooperators
- Fanpage on facebook - fb.com/tinxsat - created to encourage people to programming and creating space projects.

18

- Github organisation - github.com/tinxsat/ - addressed for programmers, data scientists. It creates opportunity to get more help from open-source developers community
- An email - tinxasat@gmail.com - created to communicate with companies, cooperators and government agencies.


19

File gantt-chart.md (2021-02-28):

# Our Gantt timeline chart

<!--

        WHAT IS MERMAID
This is something simmilar to Makrdown, offering some nice graphs and charts written in plain text

        HOW TO EDIT THIS FILE 
Below (in code block with mermaid) is mermaid-style Gantt chart (written in text).
Our GitHub action generates .png file and puts it above the code block - so you can edit the text, and the image will update after few minutes.
Below are some commets that indicate where action generates stuff - usually you should not touch such places - but in this case,
you are free to edit stuf in mermaid code block.

        HOW TO WRITE MERMAID GANTT
Here is the Gantt section of Mermaid documentation: https://mermaid-js.github.io/mermaid/diagrams-and-syntax-and-examples/gantt.html
Here is the live mermaid editor: https://mermaid-js.github.io/mermaid-live-editor/
Generally, stick to the format where you just write begin and end date
-->

<!-- generated by mermaid compile action - START -->
~mermaid diagram 1~
<details>
  <summary>Mermaid markup</summary>

```mermaid
gantt
    title TinX gantt chart
    dateFormat  YYYY-MM-DD
    
    section Designing
    PDR writing :done, 2020-10-01, 2020-10-27
    Ideas collecting :done, 2020-10-01, 2020-10-10
    Creating PoC of ideas : 2020-10-05, 2020-10-15
    Online workshops :done, 2020-10-05, 2020-10-07
    Designing mechanical structure :done, 2020-10-05, 2020-10-20
    Designing electrical structure :done, 2020-10-05, 2020-10-20
    Designing software structure :done, 2020-10-05, 2020-10-20
    
    section Constructing
    CDR writing : 2020-11-03, 2021-01-15
    Materials tests :crit, 2020-11-03, 2020-12-03
    Final budget estimation : 2020-11-25, 2020-12-03
    Soldering PCBs : 2020-12-03, 2021-01-10
    CanSat building :crit, 2020-11-03, 2021-01-10
    Assemly of final "launch candidate" :crit 2021-03-05, 2021-03-29
    
    section Testing 
    FDR writing : 2021-01-22, 2021-03-01
    Software tests :crit, 2021-01-22, 2021-02-22
    Recovery system tests :crit, 2021-01-30, 2021-02-10
    Mechanical tests :crit, 2021-02-05, 2021-02-20
    Grand test of whole system : 2021-03-01, 2021-04-01
    
    section Social works
    Social media managing : 2020-10-01, 2021-03-01
    Creating list of cooperators : 2020-10-01, 2020-10-27
    Establishing cooperation :crit, 2020-10-10, 2021-01-15
    Collecting materials about final stage : 2021-03-05, 2021-04-01
    Publication of final project summaries : 2021-03-15, 2021-05-01

```

</details>
<!-- generated by mermaid compile action - END -->

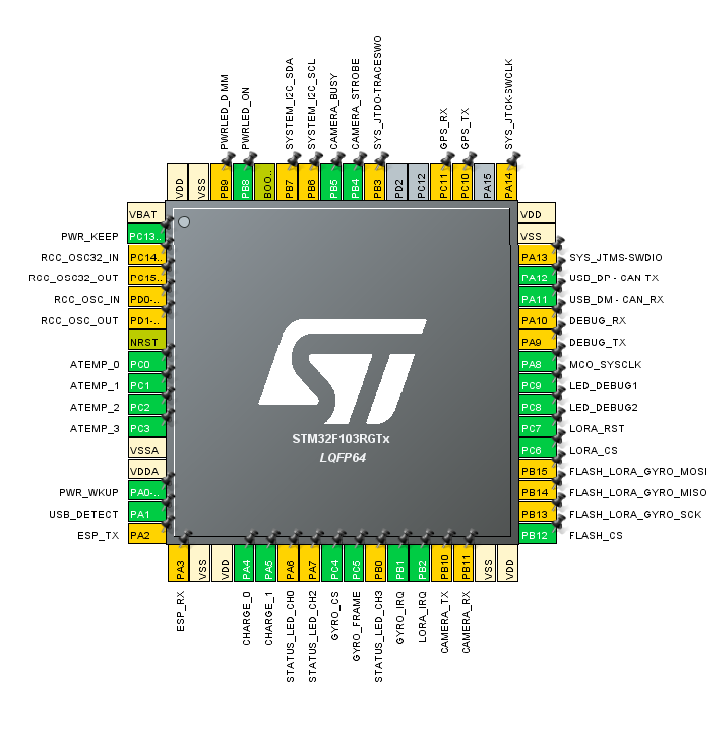
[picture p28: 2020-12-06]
images/stm.png

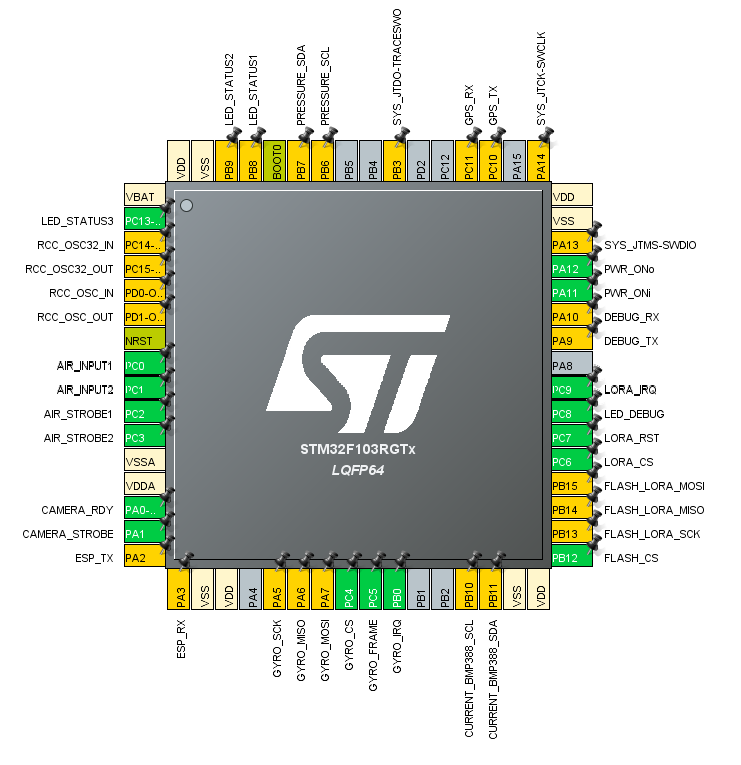
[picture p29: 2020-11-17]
images/proc-shema.png

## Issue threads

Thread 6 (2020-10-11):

Describe what's our mission

TheLastGimbus, 2020-10-11:
@miki164 is the CEO here, so please describe briefly what's our mission in this project

If we have many, give each one it's header if it will look nice

This issue is assigned to miki, but anyone is encouraged to add his ideas!

miki164, 2020-10-12:
Well here are our mission objectives I think it's good good description of our mission.

### Measurements of atmospheric pressure and temperature with  subsequent data analysis.
Key goals:
* Measure of pressure and temperature outside the cansat.
* Radio transmission of measurements data in minimal rate one packet per second.
* Calculation of altitude based on atmospheric pressure.
### Demonstration of cansat system for rescue operations during natural disasters.
Key goals:
* Design system that meet following requirements:
* low cost of produce
* high accuracy
* Access to information about position(GPS), altitude (barometer), temperature, acceleration
* Take photos from the thermovision and visible range camera.
* Mark on photos all obstacles (to protect rescuers) and places where people could possibly be.

Optional goals:
* Investigate fire resistant biofiber composite with which body of cansat will be build
* Pointing geographical coordinates of marked obstacles/humans.

TheLastGimbus, 2020-10-12:
Great, make a PR that puts that into README, with "resolves #6"

Closed 2020-10-13.

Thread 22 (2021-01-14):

Solder the PCBs

miki164, 2021-01-14:
It's work for @fifi-fifi

TheLastGimbus, 2021-01-14:
This could be marked as done by posting a PR containing the photo of soldered PCB

miki164, 2021-01-17:
Noone asked :P

Xornee, 2021-01-21:
Dzień dobry chciałbym się zorientować w cenie biletu na mecz Ligi Mistrzów

TheLastGimbus, 2021-01-21:
A jaka pana interesuje

trybuna?

miki164, 2021-01-22:
Lmao

Xornee, 2021-01-30:
Zyleta

TheLastGimbus, 2021-01-30:
Z kartą czy bez?

Closed 2021-02-28.

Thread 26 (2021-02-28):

Final tests of whole project

TheLastGimbus, 2021-02-28:
Do some full-blown test of whole system integrating with everything - CanSat talking to ground station, ground station processing it, etc

Find some nice place to drop CanSat from and test it there

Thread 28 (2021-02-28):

Test ground station data handlin

TheLastGimbus, 2021-02-28:
Test communication between LoRa ground receiver and Python server under artificially heavy load

We need to be sure that everything encodes smoothly, and won't crash if the data will be too big

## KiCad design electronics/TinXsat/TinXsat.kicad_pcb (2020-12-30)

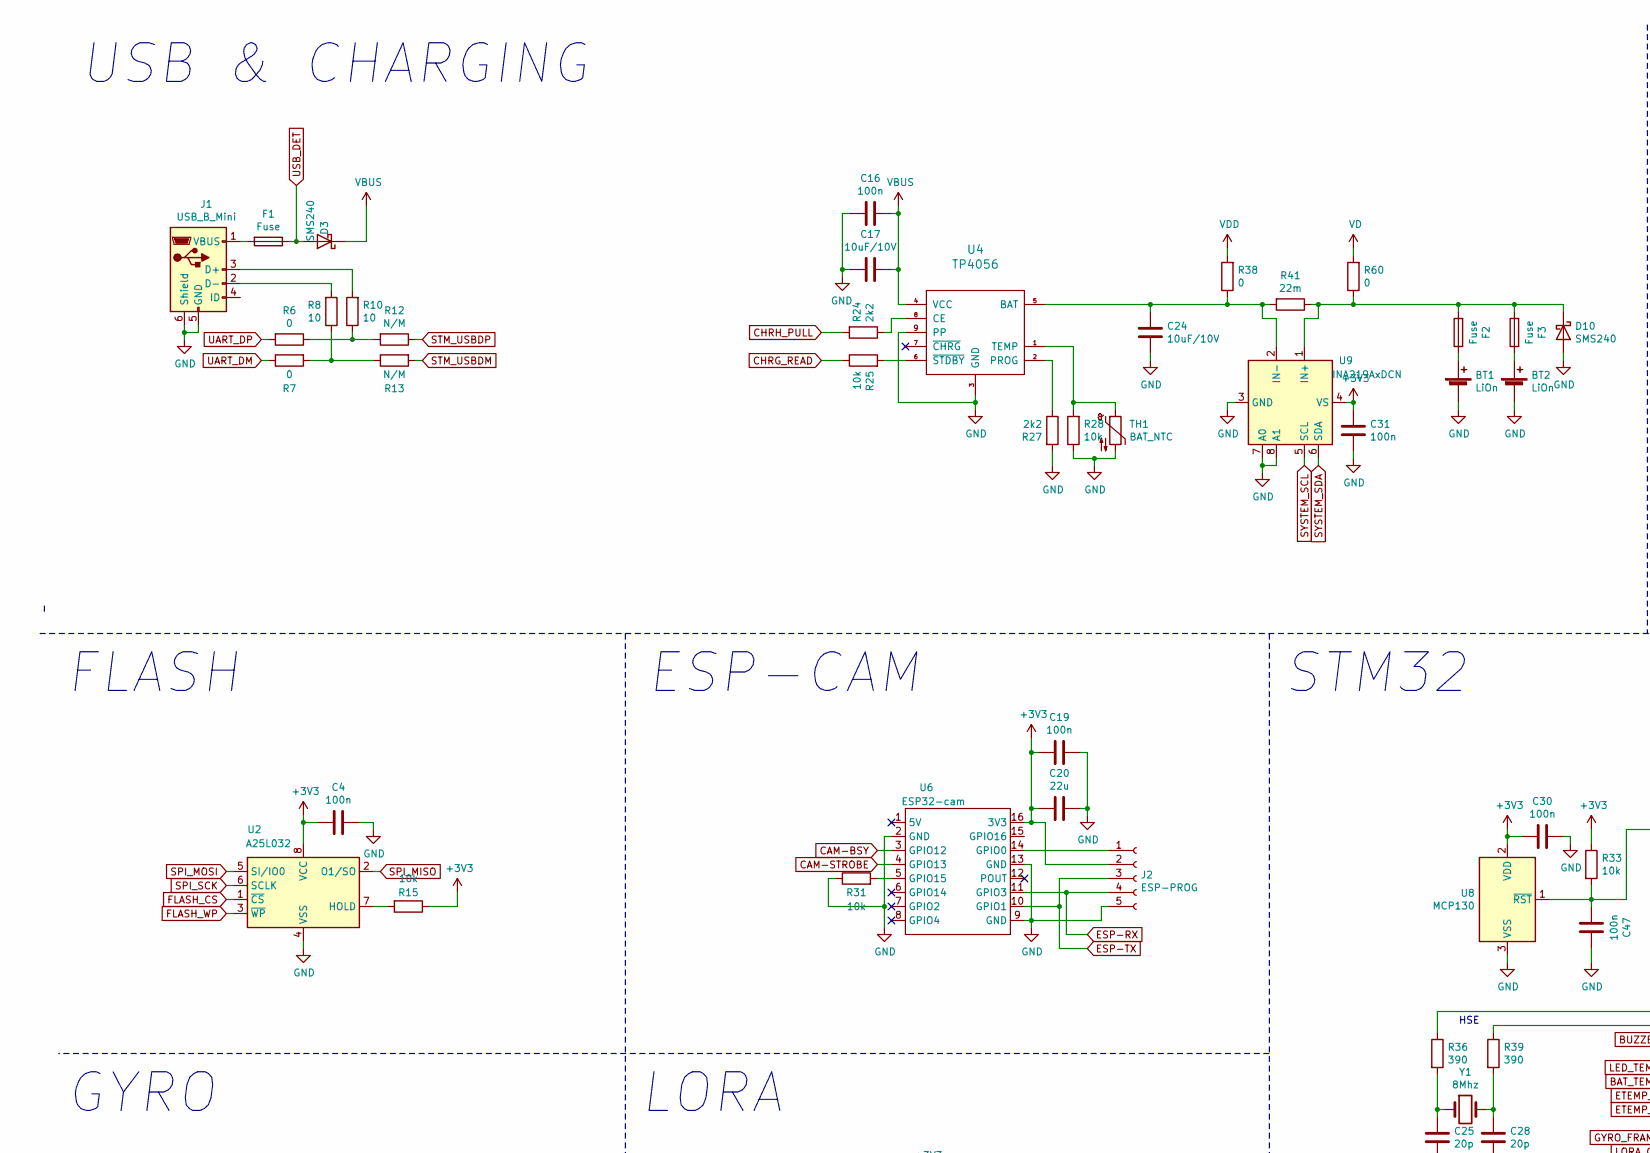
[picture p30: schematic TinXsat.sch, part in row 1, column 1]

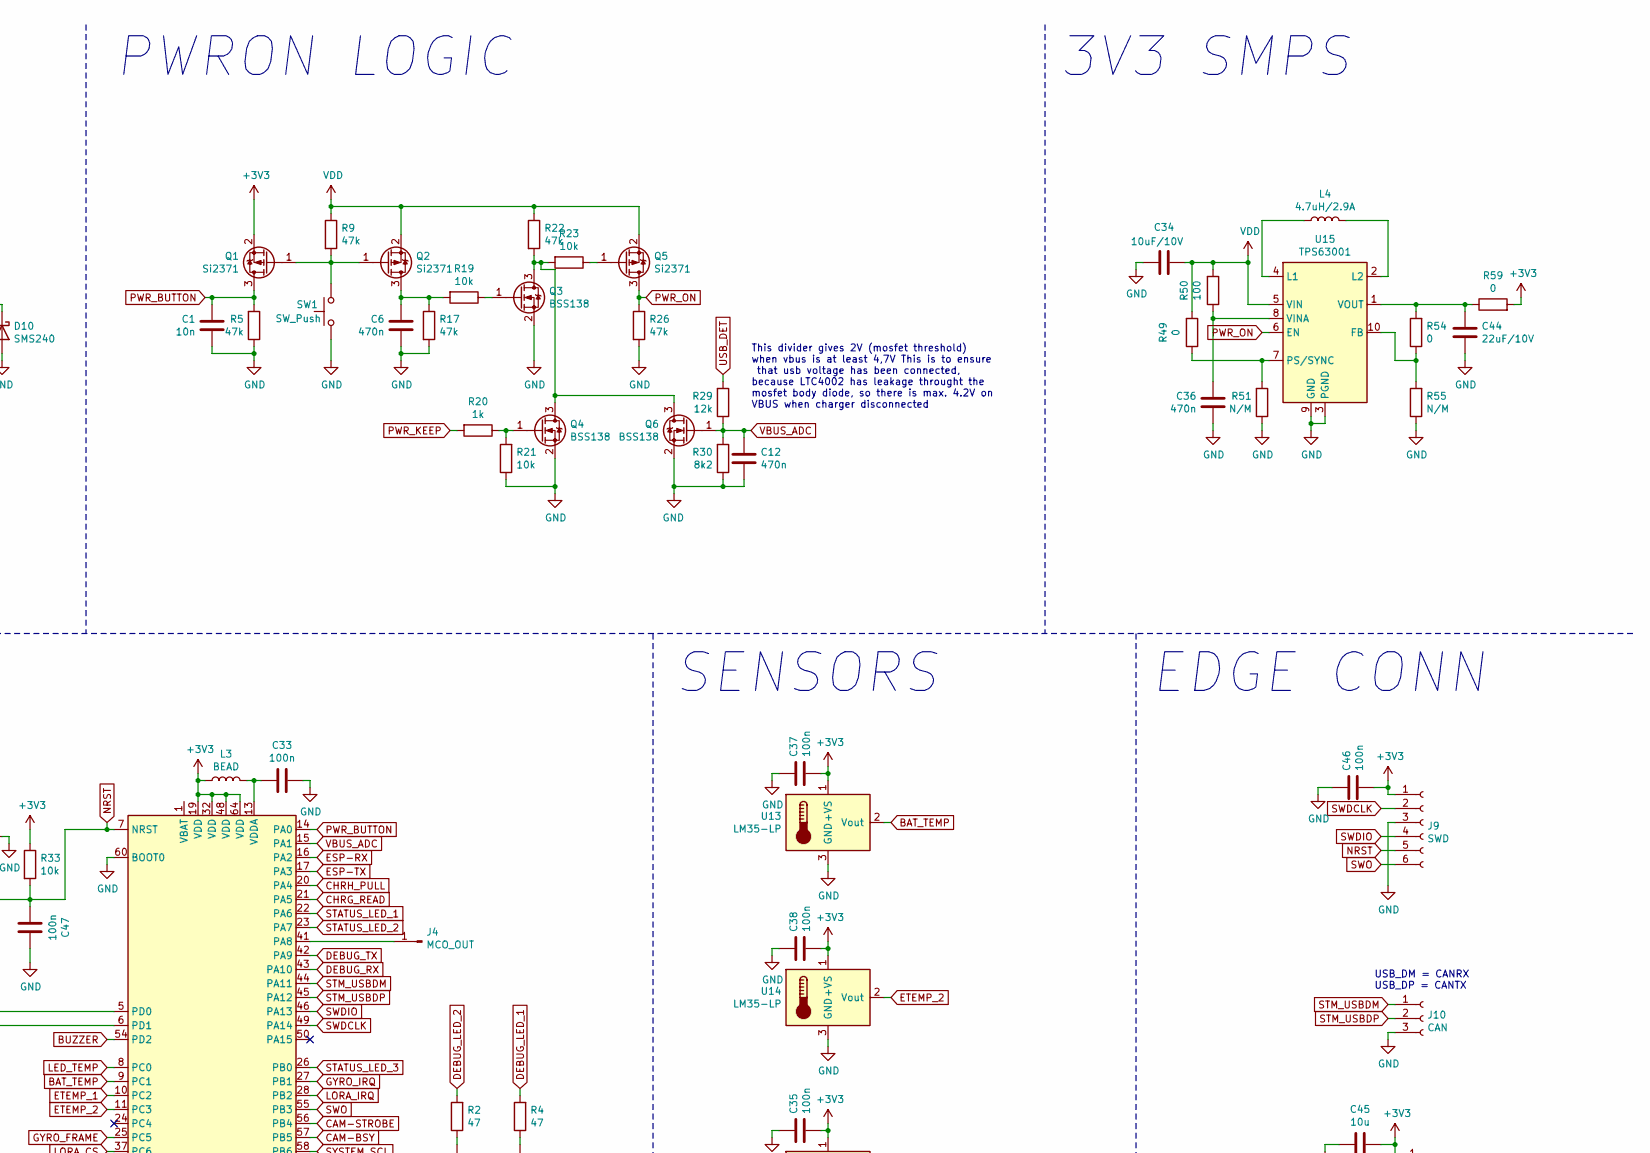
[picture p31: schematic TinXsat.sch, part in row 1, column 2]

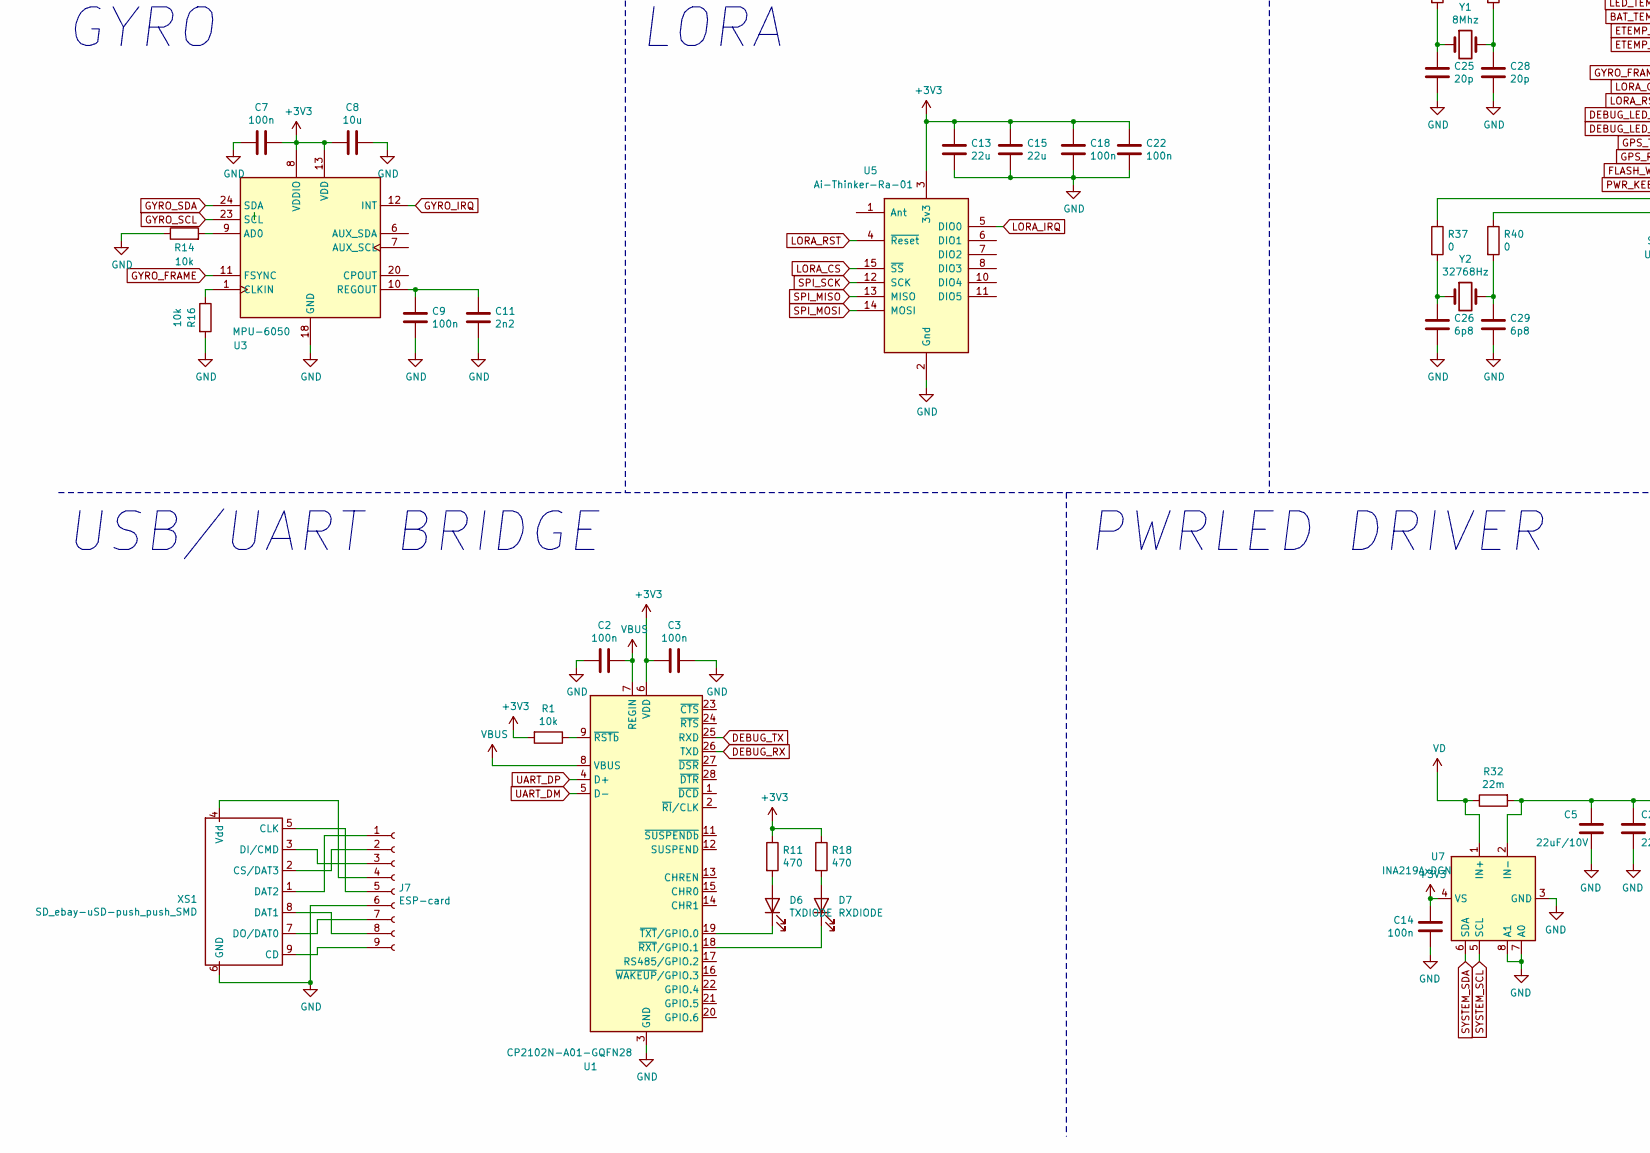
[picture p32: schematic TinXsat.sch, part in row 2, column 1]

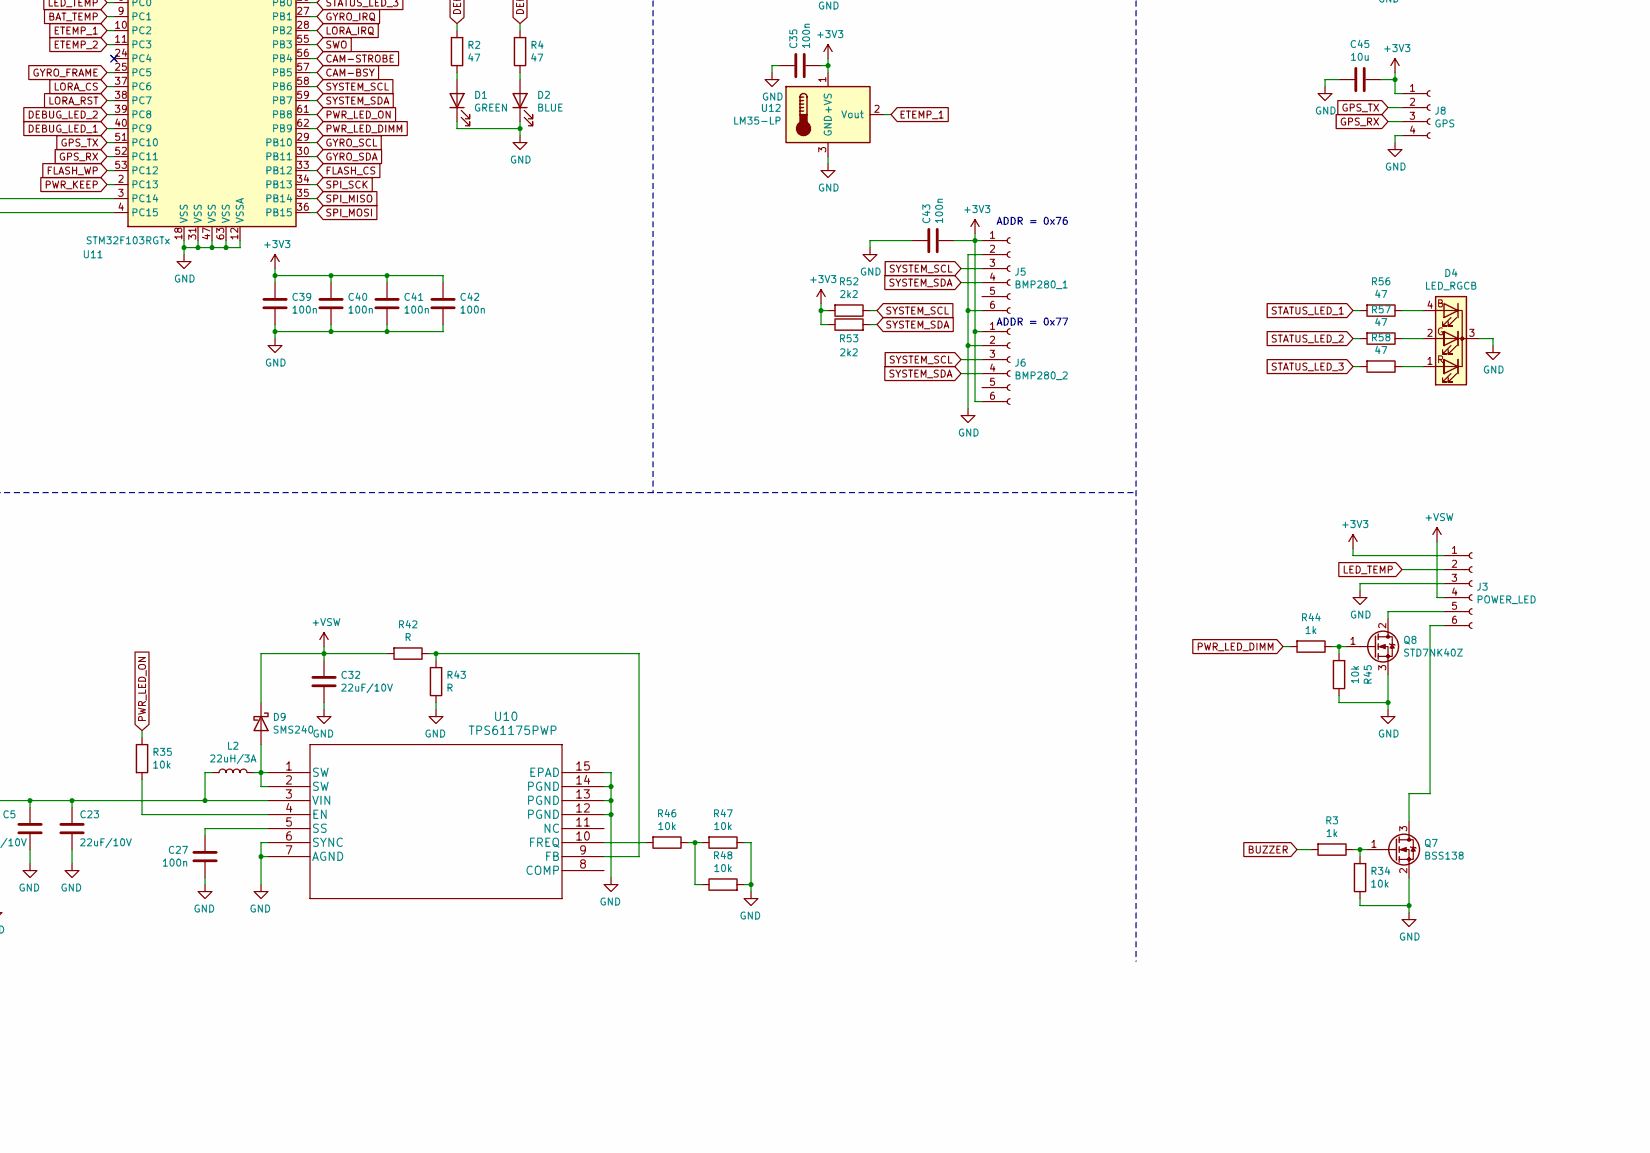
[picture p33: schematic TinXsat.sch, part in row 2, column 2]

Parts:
BT1, BT2: LiOn; BATT
C1: 10n; C_0805_2012Metric_Pad1.18x1.45mm_HandSolder
C2, C3, C4, C7, C9, C14, C16, C18, C19, C22, C27, C30, C31, C33, C35, C37, C38, C39, C40, C41, C42, C43, C46, C47: 100n; C_0805_2012Metric_Pad1.18x1.45mm_HandSolder
C5, C23, C32, C44: 22uF/10V; C_1210_3225Metric_Pad1.33x2.70mm_HandSolder
C6, C12, C36: 470n; C_0805_2012Metric_Pad1.18x1.45mm_HandSolder
C8, C45: 10u; C_1206_3216Metric_Pad1.33x1.80mm_HandSolder
C11: 2n2; C_0805_2012Metric_Pad1.18x1.45mm_HandSolder
C13, C15, C20: 22u; C_1210_3225Metric_Pad1.33x2.70mm_HandSolder
C17, C24, C34: 10uF/10V; C_1206_3216Metric_Pad1.33x1.80mm_HandSolder
C25, C28: 20p; C_0603_1608Metric_Pad1.08x0.95mm_HandSolder
C26, C29: 6p8; C_0603_1608Metric_Pad1.08x0.95mm_HandSolder
D1: GREEN; LED_0805_2012Metric_Pad1.15x1.40mm_HandSolder
D2: BLUE; LED_0805_2012Metric_Pad1.15x1.40mm_HandSolder
D3, D9, D10: SMS240; D_MELF
D4: LED_RGCB; LED_D5.0mm-4_RGB
D6: TXDIODE; LED_0805_2012Metric_Pad1.15x1.40mm_HandSolder
D7: RXDIODE; LED_0805_2012Metric_Pad1.15x1.40mm_HandSolder
F1, F2, F3: Fuse; Fuse_1206_3216Metric_Pad1.42x1.75mm_HandSolder
J1: USB_B_Mini; USB_Mini-B_Lumberg_2486_01_Horizontal
J2: ESP-PROG; PinHeader_1x05_P2mm_SMD
J3: POWER_LED; PinHeader_1x06_P2mm_SMD
J4: MCO_OUT; PinHeader_1x01_P2.54mm_Vertical
J5: BMP280_1; PinHeader_1x06_P2mm_SMD
J6: BMP280_2; PinHeader_1x06_P2mm_SMD
J7: ESP-card; PinHeader_1x08_P2mm_SMD
J8: GPS; PinHeader_1x04_P2mm_SMD
J9: SWD; PinHeader_1x06_P2mm_SMD
J10: CAN; PinHeader_1x03_P2mm_SMD
L2: 22uH/3A; L_7.3x7.3_H3.5
L3: BEAD; L_0805_2012Metric_Pad1.05x1.20mm_HandSolder
L4: 4.7uH/2.9A; L_7.3x7.3_H3.5
Q1, Q2, Q5: Si2371; SOT-23
Q3, Q4, Q6, Q7: BSS138; SOT-23
Q8: STD7NK40Z; TO-252-2
R1, R14, R15, R16, R19, R21, R23, R25, R28, R31, R33, R34, R35, R45, R46, R47, R48: 10k; R_0805_2012Metric_Pad1.20x1.40mm_HandSolder
R2, R4, R56, R57, R58: 47; R_0805_2012Metric_Pad1.20x1.40mm_HandSolder
R3, R20, R44: 1k; R_0805_2012Metric_Pad1.20x1.40mm_HandSolder
R5, R9, R17, R22, R26: 47k; R_0805_2012Metric_Pad1.20x1.40mm_HandSolder
R6, R7, R37, R38, R40, R49, R54, R59, R60: 0; R_0805_2012Metric_Pad1.20x1.40mm_HandSolder
R8, R10: 10; R_0805_2012Metric_Pad1.20x1.40mm_HandSolder
R11, R18: 470; R_0805_2012Metric_Pad1.20x1.40mm_HandSolder
R12, R13, R51, R55: N/M; R_0805_2012Metric_Pad1.20x1.40mm_HandSolder
R24, R27, R52, R53: 2k2; R_0805_2012Metric_Pad1.20x1.40mm_HandSolder
R29: 12k; R_0805_2012Metric_Pad1.20x1.40mm_HandSolder
R30: 8k2; R_0805_2012Metric_Pad1.20x1.40mm_HandSolder
R32, R41: 22m; R_MiniMELF_MMA-0204
R36, R39: 390; R_0805_2012Metric_Pad1.20x1.40mm_HandSolder
R42, R43: R; R_0805_2012Metric_Pad1.20x1.40mm_HandSolder
R50: 100; R_0805_2012Metric_Pad1.20x1.40mm_HandSolder
SW1: SW_Push; SW_Tactile_SKHH_Angled
TH1: BAT_NTC; PinHeader_1x02_P2mm_SMD
U1: CP2102N-A01-GQFN28; QFN-28-1EP_5x5mm_P0.5mm_EP3.35x3.35mm
U2: A25L032; WSON-8-1EP_6x5mm_P1.27mm_EP3.4x4mm
U3: MPU-6050; InvenSense_QFN-24_4x4mm_P0.5mm
U4: TP4056; SOIC-8-1EP_3.9x4.9mm_P1.27mm_EP2.29x3mm
U5: Ai-Thinker-Ra-01; Ai-Thinker-Ra-01-LoRa
U6: ESP32-cam; ESP32-CAM
U7, U9: INA219AxDCN; SOT-23-8
U8: MCP130; SOT-23
U10: TPS61175PWP
U11: STM32F103RGTx; LQFP-64_10x10mm_P0.5mm
U12, U13, U14: LM35-LP; PinHeader_1x03_P2mm_SMD
U15: TPS63001; Texas_DRC0010J_ThermalVias
XS1: SD_ebay-uSD-push_push_SMD; Conn_uSDcard
Y1: 8Mhz; Crystal_SMD_HC49-SD
Y2: 32768Hz; Crystal_DS26_D2.0mm_L6.0mm_Horizontal_1EP_style1

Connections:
+3V3: C3.2, C4.2, C7.1, C8.2, C13.2, C14.2, C15.2, C18.2, C19.1, C20.2, C22.2, C30.1, C31.2, C35.1, C37.1, C38.1, C39.2, C40.2, C41.2, C42.2, C43.1, C45.1, C46.1, J2.2, J3.1, J5.1, J6.1, J6.6, J8.1, J9.1, L3.1, Q1.2 (S), R1.2, R11.1, R15.1, R18.1, R33.1, R52.2, R53.1, R59.2, U1.6 (VDD), U2.8 (VCC), U3.8 (VDDIO), U3.13 (VDD), U5.3 (3v3), U6.16 (3V3), U7.4 (VS), U8.2 (VDD), U9.4 (VS), U11.19 (VDD), U11.32 (VDD), U11.48 (VDD), U11.64 (VDD), U12.1 (+VS), U13.1 (+VS), U14.1 (+VS)
+VSW: C32.1, D9.1 (K), J3.4, R42.2
BAT_TEMP: U11.9 (PC1), U13.2 (Vout)
BUZZER: R3.2, U11.54 (PD2)
CAM-BSY: U6.3 (GPIO12), U11.57 (PB5)
CAM-STROBE: U6.4 (GPIO13), U11.56 (PB4)
CHRG_READ: R25.1, U11.21 (PA5)
CHRH_PULL: R24.2, U11.20 (PA4)
DEBUG_LED_1: R4.2, U11.40 (PC9)
DEBUG_LED_2: R2.2, U11.39 (PC8)
DEBUG_RX: U1.26 (TXD), U11.43 (PA10)
DEBUG_TX: U1.25 (RXD), U11.42 (PA9)
ESP-RX: J2.4, U6.11 (GPIO3), U11.16 (PA2)
ESP-TX: J2.3, U6.10 (GPIO1), U11.17 (PA3)
ETEMP_1: U11.10 (PC2), U12.2 (Vout)
ETEMP_2: U11.11 (PC3), U14.2 (Vout)
FLASH_CS: U2.1 (~CS), U11.33 (PB12)
FLASH_WP: U2.3 (~WP~), U11.53 (PC12)
GND: BT1.2 (-), BT2.2 (-), C1.1, C2.2, C3.1, C4.1, C5.2, C6.1, C7.2, C8.1, C9.1, C11.1, C12.2, C13.1, C14.1, C15.1, C16.2, C17.1, C18.1, C19.2, C20.1, C22.1, C23.2, C24.2, C25.2, C26.2, C27.1, C28.2, C29.2, C30.2, C31.1, C32.2, C33.2, C34.2, C35.2, C36.1, C37.2, C38.2, C39.1, C40.1, C41.1, C42.1, C43.2, C44.2, C45.2, C46.2, C47.2, D1.1 (K), D2.1 (K), D4.3 (K), D10.2 (A), J1.5 (GND), J1.6 (Shield), J2.5, J3.3, J5.2, J5.6, J6.2, J7.6, J8.4, J9.3, J10.3, Q3.2 (S), Q4.2 (S), Q6.2 (S), Q7.2 (S), Q8.3 (S), R5.1, R14.1, R16.2, R17.2, R21.1, R26.2, R27.2, R28.1, R30.1, R31.1, R34.1, R43.1, R45.1, R47.1, R48.2, R51.1, R55.1, SW1.2, TH1.2, U1.3 (GND), U1.29 (GND), U2.4 (VSS), U3.18 (GND), U4.3 (GND), U4.9 (PP), U5.2 (Gnd), U5.9 (Gnd), U5.16 (Gnd), U6.2 (GND), U6.9 (GND), U6.13 (GND), U7.3 (GND), U7.7 (A0), U7.8 (A1), U8.3 (VSS), U9.3 (GND), U9.7 (A0), U9.8 (A1), U10.6 (SYNC), U10.7 (AGND), U10.12 (PGND), U10.13 (PGND), U10.14 (PGND), U10.15 (EPAD), U11.12 (VSSA), U11.18 (VSS), U11.31 (VSS), U11.47 (VSS), U11.60 (BOOT0), U11.63 (VSS), U12.3 (GND), U13.3 (GND), U14.3 (GND), U15.3 (PGND), U15.9 (GND), U15.11 (PGND), XS1.6 (GND)
GPS_RX: J8.3, U11.52 (PC11)
GPS_TX: J8.2, U11.51 (PC10)
GYRO_FRAME: U3.11 (FSYNC), U11.25 (PC5)
GYRO_IRQ: U3.12 (INT), U11.27 (PB1)
GYRO_SCL: U3.23 (SCL), U11.29 (PB10)
GYRO_SDA: U3.24 (SDA), U11.30 (PB11)
LED_TEMP: J3.2, U11.8 (PC0)
LORA_CS: U5.15 (~SS), U11.37 (PC6)
LORA_IRQ: U5.5 (DIO0), U11.28 (PB2)
LORA_RST: U5.4 (~Reset), U11.38 (PC7)
NRST: C47.1, J9.5, R33.2, U8.1 (~RST), U11.7 (NRST)
unnamed: BT1.1 (+), F2.1
unnamed: BT2.1 (+), F3.1
unnamed: C6.2, Q2.3 (D), R17.1, R19.2
unnamed: C9.2, C11.2, U3.10 (REGOUT)
unnamed: C5.1, C23.1, L2.1, R32.2, U7.2 (IN-), U10.3 (VIN)
unnamed: C24.1, R38.1, R41.2, U4.5 (BAT), U9.2 (IN-)
unnamed: C25.1, R36.2, Y1.1
unnamed: C26.1, R37.2, Y2.1
unnamed: C27.2, U10.5 (SS)
unnamed: C28.1, R39.2, Y1.2
unnamed: C29.1, R40.2, Y2.2
unnamed: C33.1, L3.2, U11.13 (VDDA)
unnamed: C36.2, R50.1, U15.8 (VINA)
unnamed: C44.1, R54.2, R59.1, U15.1 (VOUT)
unnamed: D1.2 (A), R2.1
unnamed: D2.2 (A), R4.1
unnamed: D4.1 (RA), R58.1
unnamed: D4.2 (GA), R57.1
unnamed: D4.4 (BA), R56.1
unnamed: D6.1 (K), U1.19 (~TXT~/GPIO.0)
unnamed: D6.2 (A), R11.2
unnamed: D7.1 (K), U1.18 (~RXT~/GPIO.1)
unnamed: D7.2 (A), R18.2
unnamed: D9.2 (A), L2.2, U10.1 (SW), U10.2 (SW)
unnamed: D10.1 (K), F2.2, F3.2, R41.1, R60.1, U9.1 (IN+)
unnamed: F1.2, J1.1 (VBUS)
unnamed: J1.2 (D-), R8.2
unnamed: J1.3 (D+), R10.2
unnamed: J2.1, U6.14 (GPIO0)
unnamed: J3.5, Q8.2 (D)
unnamed: J3.6, Q7.3 (D)
unnamed: J4.1, U11.41 (PA8)
unnamed: J7.1, XS1.1 (DAT2)
unnamed: J7.2, XS1.2 (CS/DAT3)
unnamed: J7.3, XS1.3 (DI/CMD)
unnamed: J7.4, XS1.4 (Vdd)
unnamed: J7.5, XS1.5 (CLK)
unnamed: J7.7, XS1.7 (DO/DAT0)
unnamed: J7.8, XS1.8 (DAT1)
unnamed: J7.9, XS1.9 (CD)
unnamed: L4.1, U15.4 (L1)
unnamed: L4.2, U15.2 (L2)
unnamed: Q1.1 (G), Q2.1 (G), R9.2, SW1.1
unnamed: Q3.1 (G), R19.1
unnamed: Q3.3 (D), Q4.3 (D), Q6.3 (D), R22.2, R23.2
unnamed: Q4.1 (G), R20.1, R21.2
unnamed: Q5.1 (G), R23.1
unnamed: Q7.1 (G), R3.1, R34.2
unnamed: Q8.1 (G), R44.1, R45.2
unnamed: R1.1, U1.9 (~RSTb)
unnamed: R6.1, R10.1, R12.2
unnamed: R7.2, R8.1, R13.1
unnamed: R14.2, U3.9 (AD0)
unnamed: R15.2, U2.7 (HOLD)
unnamed: R16.1, U3.1 (CLKIN)
unnamed: R24.1, U4.8 (CE)
unnamed: R25.2, U4.6 (~STDBY)
unnamed: R27.1, U4.2 (PROG)
unnamed: R28.2, TH1.1, U4.1 (TEMP)
unnamed: R31.2, U6.5 (GPIO15)
unnamed: R35.2, U10.4 (EN)
unnamed: R36.1, U11.5 (PD0)
unnamed: R37.1, U11.3 (PC14)
unnamed: R39.1, U11.6 (PD1)
unnamed: R40.1, U11.4 (PC15)
unnamed: R42.1, R43.2, U10.9 (FB)
unnamed: R46.1, R47.2, R48.1
unnamed: R46.2, U10.10 (FREQ)
unnamed: R49.1, R51.2, U15.7 (PS/SYNC)
unnamed: R54.1, R55.2, U15.10 (FB)
PWR_BUTTON: C1.2, Q1.3 (D), R5.2, U11.14 (PA0)
PWR_KEEP: R20.2, U11.2 (PC13)
PWR_LED_DIMM: R44.2, U11.62 (PB9)
PWR_LED_ON: R35.1, U11.61 (PB8)
PWR_ON: Q5.3 (D), R26.1, U15.6 (EN)
SPI_MISO: U2.2 (O1/SO), U5.13 (MISO), U11.35 (PB14)
SPI_MOSI: U2.5 (SI/IO0), U5.14 (MOSI), U11.36 (PB15)
SPI_SCK: U2.6 (SCLK), U5.12 (SCK), U11.34 (PB13)
STATUS_LED_1: R56.2, U11.22 (PA6)
STATUS_LED_2: R57.2, U11.23 (PA7)
STATUS_LED_3: R58.2, U11.26 (PB0)
STM_USBDM: J10.1, R13.2, U11.44 (PA11)
STM_USBDP: J10.2, R12.1, U11.45 (PA12)
SWDCLK: J9.2, U11.49 (PA14)
SWDIO: J9.4, U11.46 (PA13)
SWO: J9.6, U11.55 (PB3)
SYSTEM_SCL: J5.3, J6.3, R52.1, U7.5 (SCL), U9.5 (SCL), U11.58 (PB6)
SYSTEM_SDA: J5.4, J6.4, R53.2, U7.6 (SDA), U9.6 (SDA), U11.59 (PB7)
UART_DM: R7.1, U1.5 (D-)
UART_DP: R6.2, U1.4 (D+)
USB_DET: D3.2 (A), F1.1, R29.2
VBUS: C2.1, C16.1, C17.2, D3.1 (K), U1.7 (REGIN), U1.8 (VBUS), U4.4 (VCC)
VBUS_ADC: C12.1, Q6.1 (G), R29.1, R30.2, U11.15 (PA1)
VD: R32.1, R60.2, U7.1 (IN+)
VDD: C34.1, Q2.2 (S), Q5.2 (S), R9.1, R22.1, R38.2, R49.2, R50.2, U15.5 (VIN)

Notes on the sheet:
This divider gives 2V (mosfet threshold) when vbus is at least 4,7V This is to ensure that usb voltage has been connected, because LTC4002 has leakage throught the mosfet body diode, so there is max. 4.2V on VBUS when charger disconnected
USB_DM = CANRX USB_DP = CANTX
HSE
ADDR = 0x76
ADDR = 0x77
STM32
ESP-CAM
FLASH
GYRO
LORA
SENSORS
EDGE CONN
3V3 SMPS
PWRON LOGIC
USB & CHARGING
USB/UART BRIDGE
PWRLED DRIVER

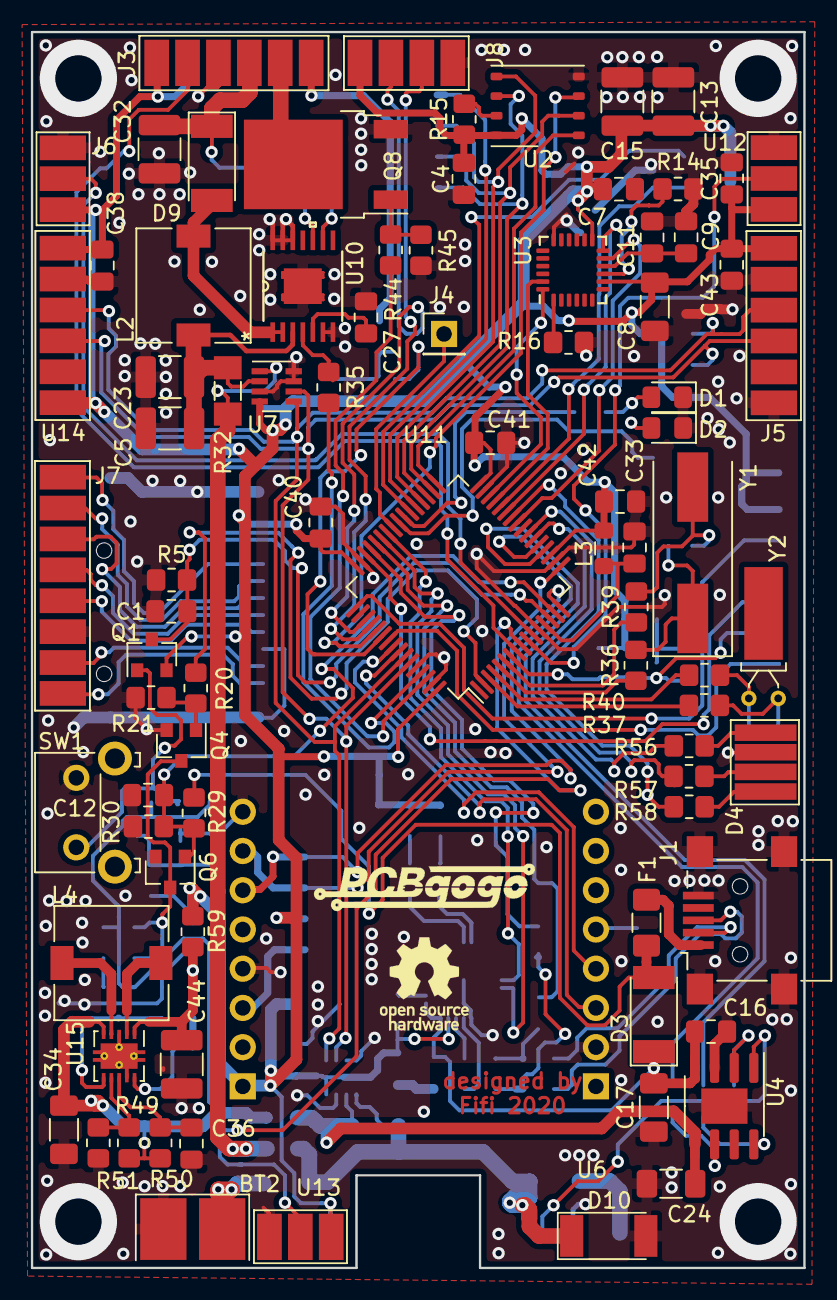
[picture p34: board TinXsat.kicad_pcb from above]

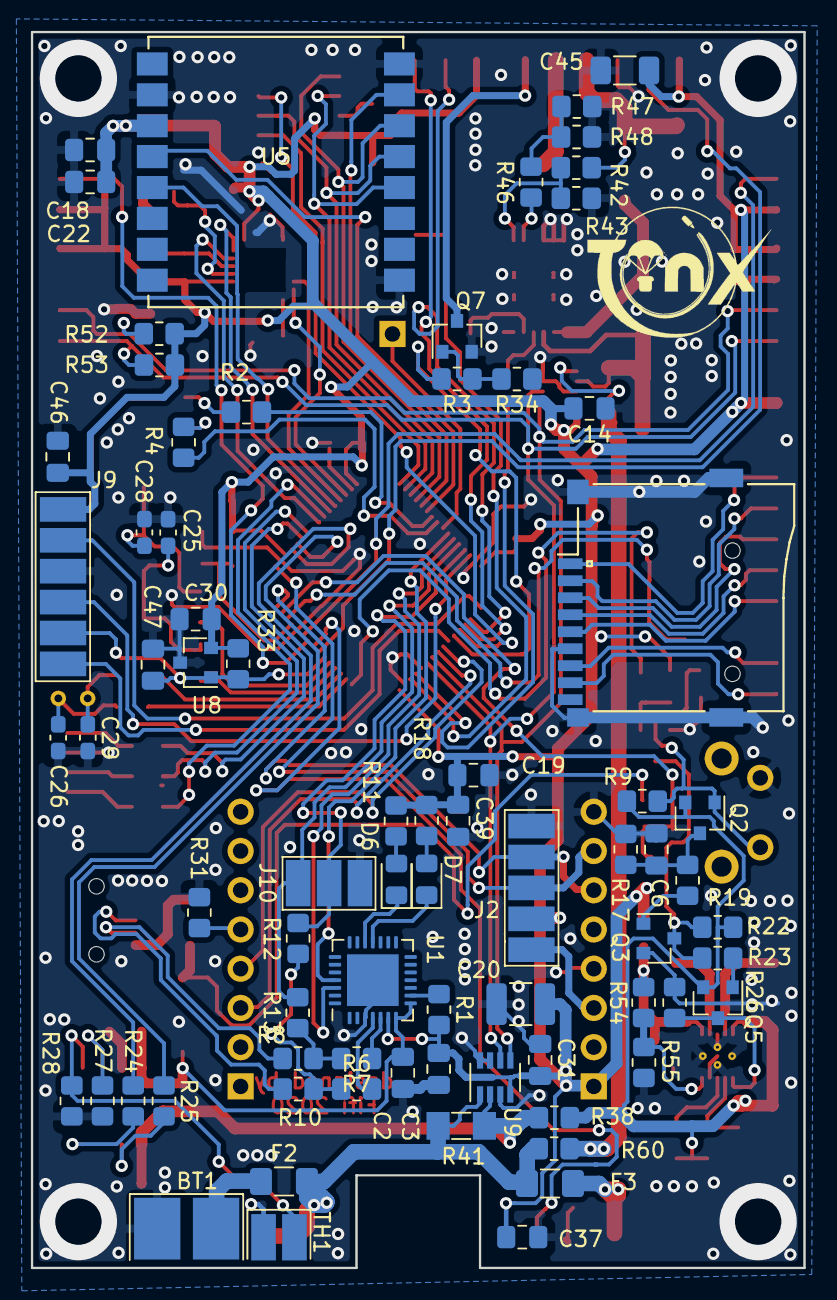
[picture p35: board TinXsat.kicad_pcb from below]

Board: 2 copper layers, 50.0 x 80.0 mm, 159 parts (74 on the bottom side), 124 nets.

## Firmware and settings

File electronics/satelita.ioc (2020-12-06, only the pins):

Mcu.UserName=STM32F103RGTx
PA0-WKUP.GPIO_Label=PWR_WKUP
PA0-WKUP.Signal=SYS_WKUP
PA1.GPIO_Label=USB_DETECT
PA1.Signal=ADCx_IN1
PA10.GPIO_Label=DEBUG_RX
PA10.Signal=USART1_RX
PA11.GPIO_Label=USB_DM - CAN_RX
PA11.Signal=USB_DM
PA12.GPIO_Label=USB_DP - CAN TX
PA12.Signal=USB_DP
PA13.Signal=SYS_JTMS-SWDIO
PA14.Signal=SYS_JTCK-SWCLK
PA2.GPIO_Label=ESP_TX
PA2.Signal=USART2_TX
PA3.GPIO_Label=ESP_RX
PA3.Signal=USART2_RX
PA4.GPIO_Label=CHARGE_0
PA4.Signal=GPIO_Output
PA5.GPIO_Label=CHARGE_1
PA5.Signal=GPIO_Input
PA6.GPIO_Label=STATUS_LED_CH0
PA6.Signal=S_TIM3_CH1
PA7.GPIO_Label=STATUS_LED_CH2
PA7.Signal=S_TIM3_CH2
PA8.GPIO_Label=MCO_SYSCLK
PA8.Signal=RCC_MCO
PA9.GPIO_Label=DEBUG_TX
PA9.Signal=USART1_TX
PB0.GPIO_Label=STATUS_LED_CH3
PB0.Signal=S_TIM3_CH3
PB1.GPIO_Label=GYRO_IRQ
PB1.Signal=GPIO_Input
PB10.GPIO_Label=CAMERA_TX
PB10.Signal=USART3_TX
PB11.GPIO_Label=CAMERA_RX
PB11.Signal=USART3_RX
PB12.GPIO_Label=FLASH_CS
PB12.Signal=GPIO_Output
PB13.GPIO_Label=FLASH_LORA_GYRO_SCK
PB13.Signal=SPI2_SCK
PB14.GPIO_Label=FLASH_LORA_GYRO_MISO
PB14.Signal=SPI2_MISO
PB15.GPIO_Label=FLASH_LORA_GYRO_MOSI
PB15.Signal=SPI2_MOSI
PB2.GPIO_Label=LORA_IRQ
PB2.Signal=GPIO_Input
PB3.Signal=SYS_JTDO-TRACESWO
PB4.GPIO_Label=CAMERA_STROBE
PB4.Signal=GPIO_Output
PB5.GPIO_Label=CAMERA_BUSY
PB5.Signal=GPIO_Input
PB6.GPIO_Label=SYSTEM_I2C_SCL
PB6.Signal=I2C1_SCL
PB7.GPIO_Label=SYSTEM_I2C_SDA
PB7.Signal=I2C1_SDA
PB8.GPIO_Label=PWRLED_ON
PB8.Signal=GPIO_Output
PB9.GPIO_Label=PWRLED_DIMM
PB9.Signal=S_TIM4_CH4
PC0.GPIO_Label=ATEMP_0
PC0.Signal=ADCx_IN10
PC1.GPIO_Label=ATEMP_1
PC1.Signal=ADCx_IN11
PC10.GPIO_Label=GPS_TX
PC10.Signal=UART4_TX
PC11.GPIO_Label=GPS_RX
PC11.Signal=UART4_RX
PC13-TAMPER-RTC.GPIO_Label=PWR_KEEP
PC13-TAMPER-RTC.Signal=GPIO_Output
PC14-OSC32_IN.Signal=RCC_OSC32_IN
PC15-OSC32_OUT.Signal=RCC_OSC32_OUT
PC2.GPIO_Label=ATEMP_2
PC2.Signal=ADCx_IN12
PC3.GPIO_Label=ATEMP_3
PC3.Signal=ADCx_IN13
PC4.GPIO_Label=GYRO_CS
PC4.Signal=GPIO_Output
PC5.GPIO_Label=GYRO_FRAME
PC5.Signal=GPIO_Output
PC6.GPIO_Label=LORA_CS
PC6.Signal=GPIO_Output
PC7.GPIO_Label=LORA_RST
PC7.Signal=GPIO_Output
PC8.GPIO_Label=LED_DEBUG2
PC8.Signal=GPIO_Output
PC9.GPIO_Label=LED_DEBUG1
PC9.Signal=GPIO_Output
PD0-OSC_IN.Signal=RCC_OSC_IN
PD1-OSC_OUT.Signal=RCC_OSC_OUT

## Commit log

2020-11-29 added schematic files
    [TinXsat.kicad_pcb, TinXsat.sch]
2020-12-06 update of pin assigments
2020-12-06 update pin assigments
2020-12-13 pcb initial commit
    [TinXsat.kicad_pcb, TinXsat.sch]
2020-12-20 pcb update (not finished yet)
    [TinXsat.kicad_pcb, TinXsat.sch]
2020-12-24 pcb final commit
    [TinXsat.kicad_pcb, TinXsat.sch]
2020-12-25 pcb gerber commit
    [TinXsat-B_Cu.gbr, TinXsat-B_Mask.gbr, TinXsat-B_SilkS.gbr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]
2020-12-30 pcb final commit after chinese changes
    [TinXsat-B_Cu.gbr, TinXsat-B_Mask.gbr, TinXsat-B_SilkS.gbr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]

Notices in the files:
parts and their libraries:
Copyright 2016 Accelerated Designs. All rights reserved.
